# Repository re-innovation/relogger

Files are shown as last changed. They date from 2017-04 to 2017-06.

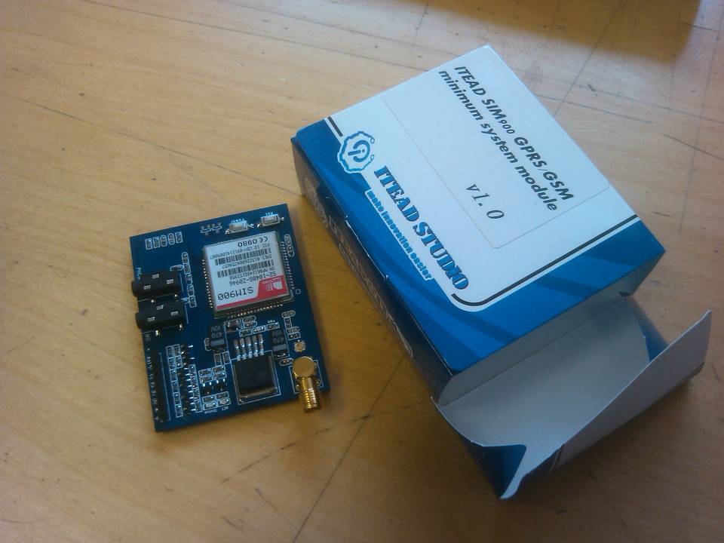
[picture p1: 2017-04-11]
relogger_Overview/GSM Equipment/GSM SIM900/Blog Post Photos/IMG_20141029_151016_copy.jpg

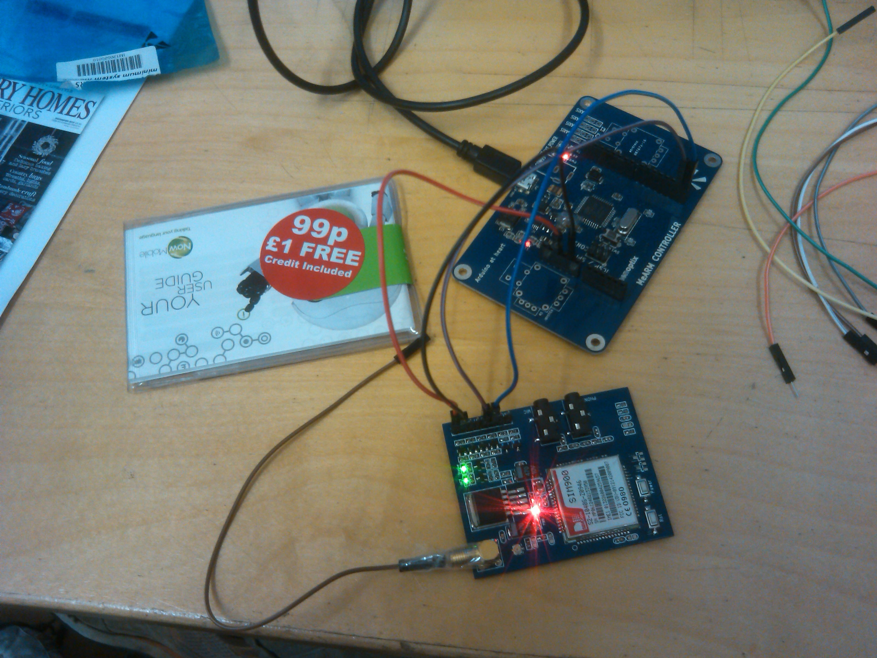
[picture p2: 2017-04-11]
relogger_Overview/GSM Equipment/GSM SIM900/Blog Post Photos/IMG_20141029_164829.jpg

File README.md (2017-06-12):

# Renewable Energy Data Logger
A multi-function renewable energy data-logger for remote logging.
This is an Arduino-based data-logger desinged to have reasanable accuracy, be low-cost, suitable for use in remote areas and to be user-friendly to set-up and use.

This is based upon work with Wind Empowerment.

This repository contains:
* An overview of the project and functions
* The Schematics and PCB design files (KiCAD)
* The Arduino control code and associated libraries
* Datasheets for all the components
* Instructions for use

# Sensors and Data
This logger can use different types of sensor attached to the inputs.

The set-up is defined on the config.txt file which must be included on the SD card.

The data required on the config.txt file is:

* Sample Time
* Sensor 1
* Sensor 2

Example config.txt file:

TO DO!

The types of sensor available are:

## Wind Speed Digital

These are conencted to a digital pin on the device.

Conversion factor required is the pulses per second to give 1m/s wind speed. 

eg: 0.6 pulse per second = 1m/s

If we read 15 pulses per second the wind speed is: 15/0.6 = 25m/s.

## Wind Speed Analog

This is connected to an analog pin.

The conversion factor is the voltage to wind speed factor.

eg. 0.1V per m/s

If we read a voltage of 0.6V then the wind speed is 0.6 / 0.1 = 6m/s

## Wind Direction

Wind direction uses a wind vane sensor with reed switches are used to introduce different resistors to the output line. Hence the output is a varying resistance, which can be measured using just one analogue pin and a potential divider.

The resistances are as follows, with all the resistors accurate to 1%. Using a potential divider of 10k for the lower resistor and a Vref of 3.3V, we can also calculate the analogue input values for each range:

* N = R1 = 33k Voltage reading = 0.76V
* NE = R2 = 8.2k Voltage reading = 1.81V
* E = R3 = 1k Voltage reading = 0.3V
* SE = R4 = 2.2k Voltage reading = 0.59V
* S = R5 = 3.9k Voltage reading = 0.92V
* SW = R6 = 16k Voltage reading = 2.03V
* W = R7 = 120k Voltage reading = 3.04V
* NW = R8 = 64.9k Voltage reading = 2.86V

## Voltage

Voltage is measured using a potential divider. R1 is the lower resistor, R2 is the top resistor.

So with R1 = 10k and R2 = 100k the real voltage is the measured voltage * (R1+R2)/(R1).

eg. V measured is 0.6V, the actual voltage will be 6.6V

We need to ensure headroom above the maximum required input voltage to ensure no damage happens to the analog input (which is protected by a zener diode). 

## Current

DC Current is measured by a range of different sensors. These generally give an output voltage which is linearly proportional to the current, but sometimes with an offset. More information here: 

https://www.re-innovation.co.uk/docs/dc-current-measurement/ 

https://www.re-innovation.co.uk/docs/acs756-current-measurements/

So we need to know the gradient and the offset for the sensor.

For the ACS758 (for example) the offset is 0.12 x Vsupply. If 5V is used as the supply voltage then the offset is 0.12 x 5 = 0.6V.
The ACS758 has a gradient of 60mV per A.

If we read 1.0V from the sensor then the conversion is: ((1.0V - offset)*1000)/ mV/A, so ((1.0-0.6)*1000)/60 = 6.66A 

The factor of 1000 converts the voltage to mV so the calculation works correctly.

## Temperature Digital

The 1-wire temeprature sensor DS18B20 is used to measure the temperature.

This requires installation of a library to read the data from this sensor, which si returned in a specific format.

## Temperature Analog

Analog temperature sensors include thermistors and thermo-couples.

These sensors will also require specific libraries to convert from the voltage readign into a temperature, as thermistors are usually non-linear.

This section needs work to implement and a decision on which type of temperature sensors uses is required.

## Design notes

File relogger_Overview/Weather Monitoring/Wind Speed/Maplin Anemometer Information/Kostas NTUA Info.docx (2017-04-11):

From 20/5/15:

(Attached Spreadsheet of data)

Hi Matt,

I managed to calibrate the anemometer. These are the calibration results:

slope offset
0.6277 0.191

The data from Ethiopia are more reasonable now.

One more question. We need to synchronize the data logger time with our DAQ card at the test site, which uses the computer time, which in turn synchronizes on the Internet.

How have you set the logger's time set?

How could we change that if needed?

Cheers
Kostas

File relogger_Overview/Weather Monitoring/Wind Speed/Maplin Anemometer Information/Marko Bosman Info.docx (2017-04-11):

From 7/5/15

Hi Matt,

this week I did my first wind measurements with the dataduino during a windy day (total one hour measurement with 1 min interval). The wind logger worked fine!

I tried to calibrate one of the cheap Maplin anemometer with an expensive (calibrated) Davis anemometer and find a big scatter, do you recognize this "trend"?:

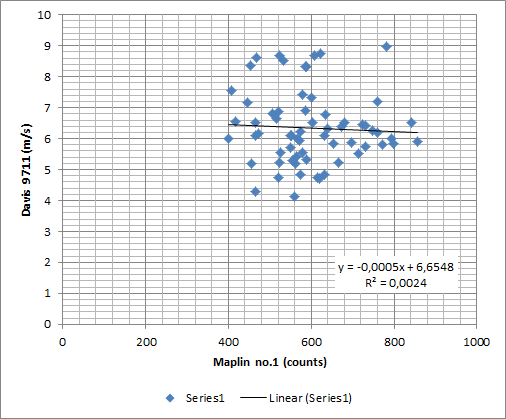
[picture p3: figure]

When I have more time again I will gather more data and will test two Maplin anemometers in parallel so I can also measure the difference between them.

keep you posted,

kind regards,

Marko Bosman

From 18/5/15:

(attached pdf)

Hi Matt,

I did some more measurements and got fairly accurate results now; see attachment. (note that the picture I have send before was wrong due to shift of time scales)

The measurement at very low windspeeds (<1 m/s) have been excluded from the dataset because the Davis anemometer is not very accurate at low wind speeds and for the purpose of wind turbine site measurements these data are not very relevant. I miss some data between 3-4 m/s, but the low and high wind speed measurements seems to correlate well. The final formula for calculating windspeed from the counts registered by the windlogger was for Anemometer 1: 0,57m/s per Hz and for Anemometer 2: 0,63m/s per Hz, somewhat different as the 0,7m/s per Hz you mentioned, but I think every Maplin anemometer is different and should be measured (periodically?).

What do you think about this procedure?

Kind regards,

Marko

From 20/5/15

(attached additional pdf)

Hi Matt,

I continued my calibration activities and finished it for 4 maplin anemometers, see attachment.

the results are pretty constant, but differ from your formula:

- Anemometer 1: 0,58 m/s per Hz
- Anemometer 2: 0,62 m/s per Hz
- Anemometer 3: 0,62 m/s per Hz
- Anemometer 4: 0,61 m/s per Hz

regards,

Marko

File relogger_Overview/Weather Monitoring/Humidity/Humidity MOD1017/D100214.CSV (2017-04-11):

Reference | Date | Time | Wind Pulses | Direction | Temperature | Humidity | Thermistor | Battery Voltage | Humidity %
AA | 10/02/2014 | 00:07:22 | 0 | D | 8.99 | 0.71084 | 10.37 | 4.44 | 71.084
AA | 10/02/2014 | 00:17:22 | 0 | D | 8.95 | 0.7117 | 10.37 | 4.44 | 71.17
AA | 10/02/2014 | 00:27:22 | 0 | D | 8.94 | 0.71218 | 10.37 | 4.44 | 71.218
AA | 10/02/2014 | 00:37:22 | 0 | D | 8.93 | 0.71218 | 10.28 | 4.44 | 71.218
AA | 10/02/2014 | 00:47:22 | 0 | D | 8.9 | 0.71237 | 10.28 | 4.44 | 71.237
AA | 10/02/2014 | 00:57:22 | 0 | D | 8.88 | 0.71279 | 10.28 | 4.44 | 71.279
AA | 10/02/2014 | 01:07:22 | 0 | D | 8.87 | 0.71279 | 10.28 | 4.44 | 71.279
AA | 10/02/2014 | 01:17:22 | 0 | D | 8.84 | 0.71304 | 10.28 | 4.44 | 71.304
AA | 10/02/2014 | 01:27:22 | 0 | D | 8.83 | 0.71322 | 10.2 | 4.43 | 71.322
AA | 10/02/2014 | 01:37:22 | 0 | D | 8.8 | 0.71322 | 10.2 | 4.43 | 71.322
AA | 10/02/2014 | 01:47:22 | 0 | D | 8.78 | 0.71347 | 10.2 | 4.43 | 71.347
AA | 10/02/2014 | 01:57:22 | 0 | D | 8.75 | 0.71347 | 10.2 | 4.43 | 71.347
AA | 10/02/2014 | 02:07:22 | 0 | D | 8.74 | 0.71408 | 10.11 | 4.43 | 71.408
AA | 10/02/2014 | 02:17:22 | 0 | D | 8.71 | 0.7145 | 10.11 | 4.43 | 71.45
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

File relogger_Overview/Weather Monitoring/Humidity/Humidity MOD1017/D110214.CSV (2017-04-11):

Reference | Date | Time | Wind Pulses | Direction | Temperature | Humidity | Thermistor | Battery Voltage
AA | 11-02-2014 | 00:00:21 | 0 | D | 10.77 | 0.64998 | 12.43 | 4.45
AA | 11-02-2014 | 00:01:21 | 0 | D | 10.76 | 0.64998 | 12.43 | 4.45
AA | 11-02-2014 | 00:02:21 | 0 | D | 10.76 | 0.64998 | 12.43 | 4.45
AA | 11-02-2014 | 00:03:21 | 0 | D | 10.76 | 0.64998 | 12.43 | 4.45
AA | 11-02-2014 | 00:04:21 | 0 | D | 10.74 | 0.65016 | 12.43 | 4.45
AA | 11-02-2014 | 00:05:21 | 0 | D | 10.74 | 0.65016 | 12.43 | 4.45
AA | 11-02-2014 | 00:06:21 | 0 | D | 10.74 | 0.65016 | 12.43 | 4.45
AA | 11-02-2014 | 00:07:21 | 0 | D | 10.73 | 0.64974 | 12.43 | 4.45
AA | 11-02-2014 | 00:08:21 | 0 | D | 10.73 | 0.65016 | 12.43 | 4.45
AA | 11-02-2014 | 00:09:21 | 0 | D | 10.73 | 0.64998 | 12.43 | 4.45
AA | 11-02-2014 | 00:10:21 | 0 | D | 10.72 | 0.64949 | 12.35 | 4.45
AA | 11-02-2014 | 00:11:21 | 0 | D | 10.72 | 0.64931 | 12.35 | 4.45
AA | 11-02-2014 | 00:12:21 | 0 | D | 10.72 | 0.65041 | 12.35 | 4.45
AA | 11-02-2014 | 00:13:21 | 0 | D | 10.70 | 0.65084 | 12.35 | 4.45
AA | 11-02-2014 | 00:14:21 | 0 | D | 10.70 | 0.65108 | 12.35 | 4.45
AA | 11-02-2014 | 00:15:21 | 0 | D | 10.70 | 0.65132 | 12.35 | 4.45
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

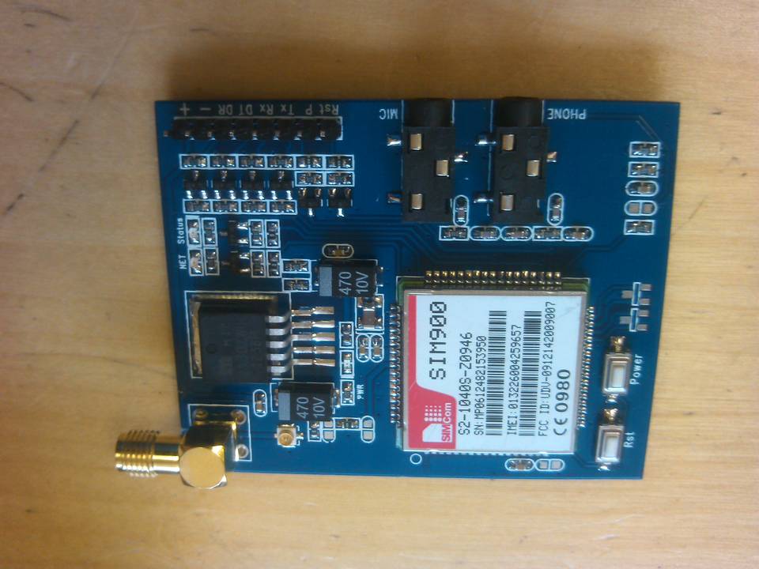
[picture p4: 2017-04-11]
relogger_Overview/GSM Equipment/GSM SIM900/Blog Post Photos/IMG_20141029_151024_copy.jpg

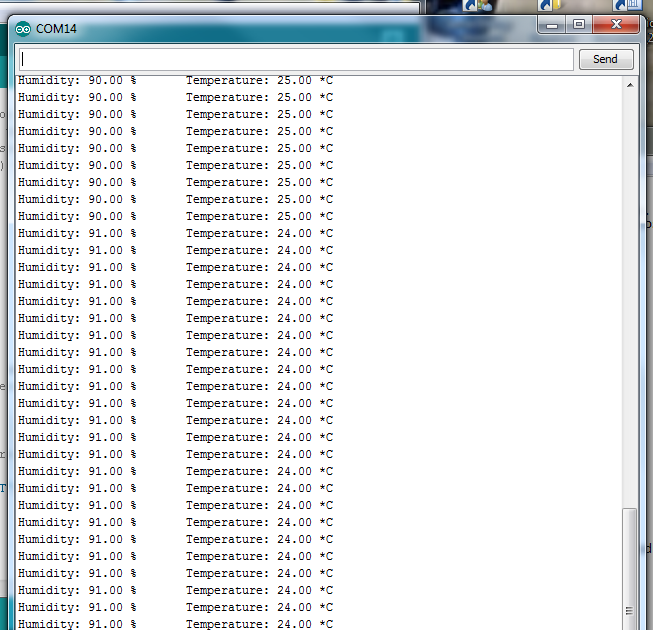
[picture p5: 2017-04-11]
relogger_Overview/Weather Monitoring/Humidity/Humidity RH11/DHT11_readings.png

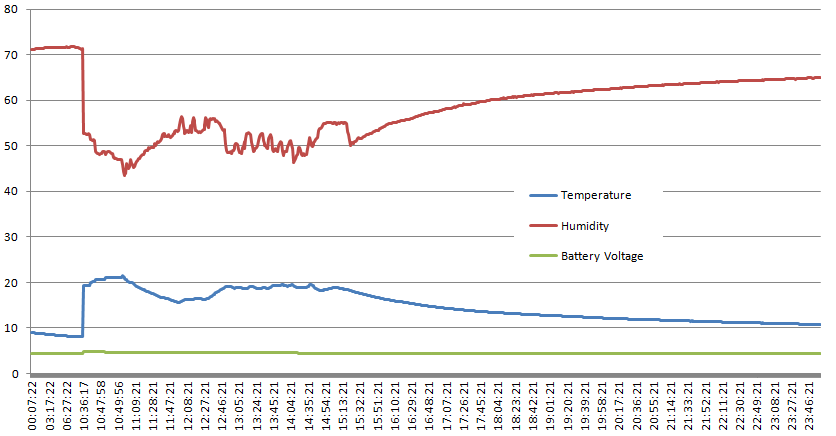
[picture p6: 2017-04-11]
relogger_Overview/Weather Monitoring/Humidity/Humidity MOD1017/TempGraph.png

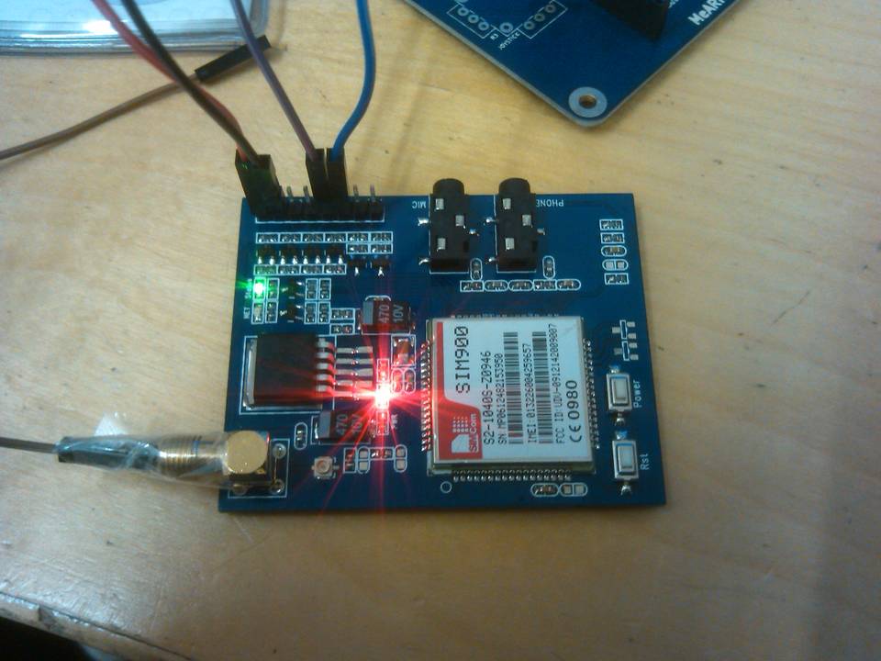
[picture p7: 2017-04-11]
relogger_Overview/GSM Equipment/GSM SIM900/Blog Post Photos/IMG_20141029_164834_copy.jpg

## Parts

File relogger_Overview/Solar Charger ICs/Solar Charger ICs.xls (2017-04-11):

Ref | IC Code | Manufacturer | Cost | Current (mA) | Voltage | Type | Package | Notes | Datasheet | Useful? | Why?
1 | N/A | AdaFruit | $17.7 | 1000 | 6 | 4.2V Li Ion |  | Module, Not IC. Uses MCP73871 | https://www.adafruit.com/product/390 | N | Module. Expensive
2 | MCP73871 | Microchip |  | 1000 | 6 | 4.2V Li Ion | 20 Lead QFN | Load Sharing IC | http://ww1.microchip.com/downloads/en/DeviceDoc/20002090C.pdf | N | Too small package
3 | MCP73831 | Microchip | 0.37 | 500 | 6 | Single Cell Li Ion | SOT-23 5 Lead | Simple. Adjustable output voltage | http://www.tme.eu/gb/Document/c098b907e182272dea149b0595062e17/mcp73831_73832.pdf | Y
4 | MCP73832 | Microchip | 0.37 | 500 | 6 | Single Cell Li Ion | SOT-23 5 Lead | As above but without tri-state output | http://www.tme.eu/gb/Document/c098b907e182272dea149b0595062e17/mcp73831_73832.pdf | Y
5 | SPV1040 | ST |  | 1500 | 0.3-5.5V | Single Cell Li Ion | TSSOP 8 | Designed for solar PV. MPPT. Needs Inductor. | http://www.st.com/content/ccc/resource/technical/document/datasheet/0d/30/c2/1a/92/03/48/cb/CD00287506.pdf/files/CD00287506.pdf/jcr:content/translations/en.CD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 | N | Not available at RS
6 | N/A | Microchip |  |  |  |  |  | Load Sharing Application Note | http://ww1.microchip.com/downloads/en/AppNotes/01149c.pdf
7 | MAX1555 | Maxim |  | 300 | 7V | Single Cell Li Ion | SOT-23-5 Lead | 2 input Li Ion Charger IC | https://www.sparkfun.com/datasheets/Components/MAX1551-MAX1555-1.pdf | Y | But Low current
8 | BQ24210 | TI | 2.26 | 800 | 20V | Single Cell Li Ion | WSON (10) | Designed for solar PV. MPPT.
9 | TP4056 | NanJing |  | 1000 | 8V | Single Cell Li Ion | SOP-8 | Design for USB input | https://dlnmh9ip6v2uc.cloudfront.net/datasheets/Prototyping/TP4056.pdf
10 | Li Po Rider Pro | SeeeedStudio |  | 1000 | 5V | Single Cell Li Ion |  | Module, Not IC. Designed for Solar and USB input. Uses CN3065 | http://www.seeedstudio.com/wiki/Lipo_Rider_Pro | N | Module
11 | CN3065 | Consonance |  | 1000 | 6V | Single Cell Li Ion |  | Used in Solar LiPo unit, but no MPPT used. | http://lib.chipdip.ru/164/DOC001164905.pdf
12 | LT1512 | Linear | 4.5 |  |  |  | DIP 8 |  | http://docs-europe.electrocomponents.com/webdocs/1364/0900766b813648fa.pdf | N | Expensive
13 | BQ2000PN-B5 | TI | 2.65 |  | 6V | Multi-Chemistry | DIP 8 | Complex external circuitry required | http://www.ti.com/lit/ds/symlink/bq2000.pdf | N | Complex additional circuitry required
14 | LT3652 | Linear | >4 | 2000 | 32V |  |  | Interesting solar charge IC | http://cds.linear.com/docs/en/datasheet/3652fe.pdf | N | Too expensive
15

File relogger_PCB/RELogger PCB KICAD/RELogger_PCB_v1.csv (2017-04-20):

Reference | Value | Footprint | Datasheet | Description | Manufacturer | Manufacturer Part No | Supplier 1 | Supplier 1 Part No | Supplier 1 Cost | Obtained?
HOLE1 | CONN_1 | REInnovationFootprint:3mm_hole_relogger |  |  |  |  |  |  |  | N/A
R1 | 470k | REInnovationFootprint:TH_Resistor_1 |  |  |  |  |  |  |  | Y
R2 | 47k | REInnovationFootprint:TH_Resistor_1 |  |  |  |  |  |  |  | Y
SW1 | CALIBRATE | REInnovationFootprint:SIL-2_large_hole |  |  |  |  |  |  |  | Y
P3 | SOLAR | REInnovationFootprint:SIL_2_screw_+_JST_2mm |  |  |  |  |  |  |  | Y
P2 | BATTERY | REInnovationFootprint:SIL_2_screw_+_JST_2mm |  |  |  |  |  |  |  | Y
P4 | A_IN_01 | matts_components:SIL-4_Grove_SIL |  |  |  |  |  |  |  | Y
PCB1 | CONN_1 |  |  |  |  |  |  |  |  | Y
LOGO1 | CONN_1 | CuriousElectric3:CEC_Globe_10mm_FCU |  |  |  |  |  |  |  | N/A
P1 | EXTERNAL PSU | REInnovationFootprint:SIL-2_screw_terminal |  |  |  |  |  |  |  | Y
P6 | I2C_1 | matts_components:SIL-4_Grove_SIL |  |  |  |  |  |  |  | Y
P7 | I2C_2 | matts_components:SIL-4_Grove_SIL |  |  |  |  |  |  |  | Y
P5 | A_IN_23 | matts_components:SIL-4_Grove_SIL |  |  |  |  |  |  |  | Y
P8 | V_EXT | REInnovationFootprint:SIL-2_screw_terminal |  |  |  |  |  |  |  | Y
D1 | 5V1 | REInnovationFootprint:TH_Diode_1 |  |  |  |  |  |  |  | Y
D2 | 5V1 | REInnovationFootprint:TH_Diode_1 |  |  |  |  |  |  |  | Y
D3 | 5V1 | REInnovationFootprint:TH_Diode_1 |  |  |  |  |  |  |  | Y
D4 | 5V1 | REInnovationFootprint:TH_Diode_1 |  |  |  |  |  |  |  | Y
P11 | SERIAL | matts_components:SIL-4_Grove_SIL |  |  |  |  |  |  |  | Y
P14 | AC_IN | REInnovationFootprint:SIL-2_screw_terminal |  |  |  |  |  |  |  | Y
K1 | ANEMOM1 | REInnovationFootprint:SIL-3_screw_terminal |  |  |  |  |  |  |  | Y
F2 | 100mA | REInnovationFootprint:TH_MC36188_FUSE
R3 | 100k | REInnovationFootprint:TH_Resistor_1 |  |  |  |  |  |  |  | Y
R4 | 100k | REInnovationFootprint:TH_Resistor_1 |  |  |  |  |  |  |  | Y
P15 | ANEMOM2 | REInnovationFootprint:SIL-2_screw_terminal |  |  |  |  |  |  |  | Y
P12 | SOFT_SERIAL | matts_components:SIL-4_Grove_SIL |  |  |  |  |  |  |  | Y
F1 | 500mA | REInnovationFootprint:TH_MC36201_FUSE
R5 | 10k | REInnovationFootprint:TH_Resistor_1 |  |  |  |  |  |  |  | Y
P10 | VANE | REInnovationFootprint:SIL-2_screw_terminal |  |  |  |  |  |  |  | Y
P9 | 3V3_VREF | REInnovationFootprint:SM_2_SLDR_JMP |  |  |  |  |  |  |  | Y
P13 | D6_D7 | matts_components:SIL-4_Grove_SIL |  |  |  |  |  |  |  | Y
DISP1 | OLED_I2C | REInnovationFootprint:TH_OLED1306
U1 | MCP3208 | REInnovationFootprint:DIP-16__300_ELL | http://docs-europe.electrocomponents.com/webdocs/1380/0900766b81380b03.pdf | 8 Channel SPI ADC 12 Bit | Microchip | MCP3208-CI/P | RS | 379-2516 | 2.716
C1 | 100n | matts_components:C1_wide_lg_pad |  |  |  |  |  |  |  | Y
P22 | A_IN_45 | matts_components:SIL-4_Grove_SIL |  |  |  |  |  |  |  | Y
P23 | AGND_GND | REInnovationFootprint:SM_2_SLDR_JMP |  |  |  |  |  |  |  | Y
D7 | 5V1 | REInnovationFootprint:TH_Diode_1 |  |  |  |  |  |  |  | Y
D5 | 5V1 | REInnovationFootprint:TH_Diode_1 |  |  |  |  |  |  |  | Y
D8 | 5V1 | REInnovationFootprint:TH_Diode_1 |  |  |  |  |  |  |  | Y
D6 | 5V1 | REInnovationFootprint:TH_Diode_1 |  |  |  |  |  |  |  | Y
D9 | 5V1 | REInnovationFootprint:TH_Diode_1 |  |  |  |  |  |  |  | Y
SW2 | SW_PUSH_SMALL_H | REInnovationFootprint:SW_PUSH_SMALL_lg_pad |  |  |  |  |  |  |  | Y
SW4 | SW_PUSH_SMALL_H | REInnovationFootprint:SW_PUSH_SMALL_lg_pad |  |  |  |  |  |  |  | Y
D17 | WS2811_EpiStar_8mm | REInnovationFootprint:TH_WS2811_LED_8mm |  |  |  |  |  |  |  | Y
EN1 | CONN_1 |  |  |  |  |  |  |  |  | N/A
LOGO2 | CONN_1 | CuriousElectric3:TCEC_Words_13mm |  |  |  |  |  |  |  | N/A
J3 | MICRO_SD | REInnovationFootprint:TH_SD_MODULE
J2 | Arduino_Nano_Header | REInnovationFootprint:NANO_DIP_30_600 |  |  |  |  |  |  |  | Y
J1 | RTC_MODULE | REInnovationFootprint:TH_RTC_MODULE
C13 | 10uF | REInnovationFootprint:C_1V7_TH |  |  |  |  |  |  |  | Y
C11 | 10uF | REInnovationFootprint:C_1V7_TH |  |  |  |  |  |  |  | Y
R17 | 2k | REInnovationFootprint:TH_Resistor_1
R16 | 470 | REInnovationFootprint:TH_Resistor_1 |  |  |  |  |  |  |  | Y
C10 | 4.7uf | REInnovationFootprint:C_1V7_TH
C14 | 4.7uf | REInnovationFootprint:C_1V7_TH
U3 | LM2574 | REInnovationFootprint:DIP-8_300_ELL | http://www.ti.com/lit/ds/symlink/lm2574.pdf | 0.5A step down DC-DC | TI | LM2574 | RS |  |  | Y
C9 | 22uF | REInnovationFootprint:C_1V7_TH |  |  |  |  |  |  |  | Y
C12 | 220uF | REInnovationFootprint:C_1V7_TH |  |  |  |  |  |  |  | Y
L1 | 330uH | REInnovationFootprint:TH_Inductor |  |  |  |  |  |  |  | Y
D10 | 1N5819 | REInnovationFootprint:TH_Diode_1 |  |  |  |  |  |  |  | Y
U5 | MCP73832 | REInnovationFootprint:SM_SOT-23-5 | http://ww1.microchip.com/downloads/en/DeviceDoc/20001984g.pdf | 500mA Linear Charge control IC | Microchip | MCP73832T-2DCI/OT | RS | 738-6629 | 0.446
D11 | D_Schottky | REInnovationFootprint:TH_Diode_1
D12 | D_Schottky | REInnovationFootprint:TH_Diode_1
Q2 | RFU9110PBF | REInnovationFootprint:TO220_P_FET | http://docs-europe.electrocomponents.com/webdocs/0791/0900766b807912ad.pdf | 3.1A P FET | Vishay | RFU9110PBF | RS | 541-1663 | 0.24
D14 | D_Schottky | REInnovationFootprint:TH_Diode_1
R18 | 100k | REInnovationFootprint:TH_Resistor_1 |  |  |  |  |  |  |  | Y
D13 | CHRG | REInnovationFootprint:TH_LED-5MM_larg_pad |  |  |  |  |  |  |  | Y
SW3 | ON/OFF | matts_components:SW_SPDT_rapid_760271 |  |  |  |  |  |  |  | Y
D18 | D_Schottky | REInnovationFootprint:TH_Diode_1
U2 | MCP1826S | REInnovationFootprint:TO220_MCP1826S
OPTO1 | VO615A | REInnovationFootprint:DIP-4_300_ELL | http://docs-europe.electrocomponents.com/webdocs/1196/0900766b81196e5a.pdf | Opto-coupler | Vishay | VO615A-5 | RS | 773-3693 | 0.12
R19 | 1k | REInnovationFootprint:TH_Resistor_1 |  |  |  |  |  |  |  | Y
D15 | 1N4001 | REInnovationFootprint:TH_Diode_1 |  |  |  |  |  |  |  | Y
R20 | 10k | REInnovationFootprint:TH_Resistor_1 |  |  |  |  |  |  |  | Y
U6 | LM393 | REInnovationFootprint:DIP-8_300_ELL | http://docs-europe.electrocomponents.com/webdocs/13e4/0900766b813e452a.pdf | Op Amp | ON Semi | LM393NG | RS | 463-870 | 0.25
RV1 | 100k | REInnovationFootprint:RV_various_lg_pad |  |  |  |  |  |  |  | Y
P26 | JMP_HALL | REInnovationFootprint:SM_2_SLDR_JMP |  |  |  |  |  |  |  | Y
D16 | 5V1 | REInnovationFootprint:TH_Diode_1 |  |  |  |  |  |  |  | Y

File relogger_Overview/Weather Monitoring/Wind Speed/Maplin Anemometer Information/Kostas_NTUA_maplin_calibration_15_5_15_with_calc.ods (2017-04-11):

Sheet: Raw Data
Reference | Date | Time | Wind1 | Wind2 | Direction | Voltage | Current1 | Current2 | Reference speed (m/s) | Expanded uncert. Uref (m/s) | average count
 |  |  |  |  |  |  |  |  | 4.023 | 0.056 | 6.1551724138
1 | 15-05-2015 | 08:21:36 | 0 | 6 | N | 15.31 | 424 | 428 | 6.082 | 0.044 | 9.0821917808
1 | 15-05-2015 | 08:21:37 | 0 | 7 | N | 10.07 | 343 | 345 | 8.13 | 0.046 | 12.632183908
1 | 15-05-2015 | 08:21:38 | 0 | 6 | N | 9.66 | 302 | 305 | 10.204 | 0.052 | 15.828125
1 | 15-05-2015 | 08:21:39 | 0 | 6 | N | 9.61 | 296 | 298 | 12.127 | 0.062 | 19.0519480519
1 | 15-05-2015 | 08:21:40 | 0 | 6 | N | 9.61 | 291 | 292 | 14.25 | 0.07 | 22.5466666667
1 | 15-05-2015 | 08:21:41 | 0 | 5 | N | 12.41 | 318 | 320 | 16.01 | 0.08 | 24.9137931034
1 | 15-05-2015 | 08:21:42 | 0 | 7 | N | 9.21 | 325 | 326 | 15.015 | 0.074 | 23.6451612903
1 | 15-05-2015 | 08:21:43 | 0 | 7 | N | 9.46 | 294 | 295 | 13.042 | 0.066 | 20.6153846154
1 | 15-05-2015 | 08:21:44 | 0 | 6 | N | 9.51 | 288 | 290 | 11.1 | 0.056 | 17.5157894737
1 | 15-05-2015 | 08:21:45 | 0 | 6 | N | 9.56 | 288 | 290 | 8.973 | 0.05 | 14.0422535211
1 | 15-05-2015 | 08:21:46 | 0 | 5 | N | 12.26 | 312 | 314 | 6.954 | 0.044 | 10.8039215686
1 | 15-05-2015 | 08:21:47 | 0 | 7 | N | 11.75 | 333 | 333 | 4.938 | 0.046 | 7.6823529412
1 | 15-05-2015 | 08:21:48 | 0 | 7 | N | 8.95 | 296 | 297
1 | 15-05-2015 | 08:21:49 | 0 | 6 | N | 9.41 | 287 | 289
1 | 15-05-2015 | 08:21:50 | 0 | 6 | N | 9.61 | 288 | 290
1 | 15-05-2015 | 08:21:51 | 0 | 5 | N | 12.26 | 309 | 311
1 | 15-05-2015 | 08:21:52 | 0 | 7 | N | 9.21 | 325 | 325
1 | 15-05-2015 | 08:21:53 | 0 | 7 | N | 9.41 | 290 | 292
1 | 15-05-2015 | 08:21:54 | 0 | 6 | N | 9.51 | 287 | 290
1 | 15-05-2015 | 08:21:55 | 0 | 6 | N | 9.61 | 286 | 288
1 | 15-05-2015 | 08:21:56 | 0 | 5 | N | 12.26 | 324 | 325
1 | 15-05-2015 | 08:21:57 | 0 | 7 | N | 9.16 | 306 | 306
1 | 15-05-2015 | 08:21:58 | 0 | 6 | N | 9.41 | 287 | 290
1 | 15-05-2015 | 08:21:59 | 0 | 6 | N | 9.56 | 288 | 289
1 | 15-05-2015 | 08:22:00 | 0 | 5 | N | 12.31 | 316 | 318
1 | 15-05-2015 | 08:22:01 | 0 | 7 | N | 9.16 | 316 | 316
1 | 15-05-2015 | 08:22:02 | 0 | 6 | N | 9.41 | 288 | 291
1 | 15-05-2015 | 08:22:03 | 0 | 6 | N | 9.51 | 289 | 291
1 | 15-05-2015 | 08:22:04 | 0 | 5 | N | 12.21 | 306 | 307
1 | 15-05-2015 | 08:22:05 | 0 | 7 | N | 11.7 | 333 | 333
1 | 15-05-2015 | 08:22:06 | 0 | 7 | N | 8.95 | 294 | 295
1 | 15-05-2015 | 08:22:07 | 0 | 6 | N | 9.36 | 286 | 289
1 | 15-05-2015 | 08:22:08 | 0 | 6 | N | 9.51 | 288 | 289
1 | 15-05-2015 | 08:22:09 | 0 | 5 | N | 12.26 | 305 | 306
1 | 15-05-2015 | 08:22:10 | 0 | 7 | N | 11.85 | 332 | 334
1 | 15-05-2015 | 08:22:11 | 0 | 7 | N | 8.95 | 305 | 306
1 | 15-05-2015 | 08:22:12 | 0 | 6 | N | 9.31 | 287 | 290
1 | 15-05-2015 | 08:22:13 | 0 | 6 | N | 9.46 | 286 | 287
1 | 15-05-2015 | 08:22:14 | 0 | 5 | N | 12.16 | 311 | 313
1 | 15-05-2015 | 08:22:15 | 0 | 7 | N | 9.05 | 308 | 308
1 | 15-05-2015 | 08:22:16 | 0 | 6 | N | 9.36 | 286 | 289
1 | 15-05-2015 | 08:22:17 | 0 | 6 | N | 9.51 | 287 | 289
1 | 15-05-2015 | 08:22:18 | 0 | 5 | N | 12.26 | 312 | 314
1 | 15-05-2015 | 08:22:19 | 0 | 7 | N | 9.16 | 320 | 320
1 | 15-05-2015 | 08:22:20 | 0 | 7 | N | 9.36 | 284 | 286
1 | 15-05-2015 | 08:22:21 | 0 | 6 | N | 9.46 | 287 | 289
1 | 15-05-2015 | 08:22:22 | 0 | 5 | N | 12.16 | 300 | 302
1 | 15-05-2015 | 08:22:23 | 0 | 7 | N | 11.75 | 329 | 330
1 | 15-05-2015 | 08:22:24 | 0 | 7 | N | 8.95 | 306 | 307
1 | 15-05-2015 | 08:22:25 | 0 | 6 | N | 9.31 | 286 | 289
1 | 15-05-2015 | 08:22:26 | 0 | 6 | N | 9.51 | 287 | 289
1 | 15-05-2015 | 08:22:27 | 0 | 5 | N | 12.21 | 308 | 310
1 | 15-05-2015 | 08:22:28 | 0 | 7 | N | 11.75 | 335 | 336
1 | 15-05-2015 | 08:22:29 | 0 | 7 | N | 8.95 | 294 | 297
1 | 15-05-2015 | 08:22:30 | 0 | 6 | N | 9.31 | 286 | 289
1 | 15-05-2015 | 08:22:31 | 0 | 6 | N | 9.46 | 287 | 288
1 | 15-05-2015 | 08:22:32 | 0 | 6 | N | 9.56 | 287 | 288
1 | 15-05-2015 | 08:22:33 | 0 | 6 | N | 12.26 | 325 | 327
1 | 15-05-2015 | 08:22:34 | 0 | 8 | N | 9.1 | 301 | 301
1 | 15-05-2015 | 08:22:35 | 0 | 7 | N | 9.36 | 298 | 299
1 | 15-05-2015 | 08:22:36 | 0 | 7 | N | 9.46 | 305 | 306
1 | 15-05-2015 | 08:22:37 | 0 | 8 | N | 12.21 | 302 | 305
1 | 15-05-2015 | 08:22:38 | 0 | 9 | N | 9 | 302 | 302
1 | 15-05-2015 | 08:22:39 | 0 | 8 | N | 9.36 | 287 | 290
1 | 15-05-2015 | 08:22:40 | 0 | 8 | N | 9.51 | 289 | 291
1 | 15-05-2015 | 08:22:41 | 0 | 7 | N | 12.16 | 299 | 300
1 | 15-05-2015 | 08:22:42 | 0 | 10 | N | 9.1 | 288 | 289
1 | 15-05-2015 | 08:22:43 | 0 | 8 | N | 9.36 | 287 | 288
1 | 15-05-2015 | 08:22:44 | 0 | 8 | N | 9.51 | 308 | 309
1 | 15-05-2015 | 08:22:45 | 0 | 9 | N | 12.21 | 318 | 321
1 | 15-05-2015 | 08:22:46 | 0 | 10 | N | 9.1 | 287 | 288
1 | 15-05-2015 | 08:22:47 | 0 | 8 | N | 9.41 | 296 | 296
1 | 15-05-2015 | 08:22:48 | 0 | 8 | N | 12.11 | 312 | 315
1 | 15-05-2015 | 08:22:49 | 0 | 10 | N | 9.1 | 297 | 297
1 | 15-05-2015 | 08:22:50 | 0 | 8 | N | 9.46 | 288 | 291
1 | 15-05-2015 | 08:22:51 | 0 | 9 | N | 9.51 | 316 | 317
1 | 15-05-2015 | 08:22:52 | 0 | 10 | N | 9.56 | 289 | 290
1 | 15-05-2015 | 08:22:53 | 0 | 9 | N | 9.66 | 288 | 290
1 | 15-05-2015 | 08:22:54 | 0 | 8 | N | 12.11 | 320 | 322
1 | 15-05-2015 | 08:22:55 | 0 | 10 | N | 9.1 | 303 | 304
1 | 15-05-2015 | 08:22:56 | 0 | 10 | N | 9.41 | 284 | 286
1 | 15-05-2015 | 08:22:57 | 0 | 8 | N | 12.21 | 307 | 309
1 | 15-05-2015 | 08:22:58 | 0 | 10 | N | 9.16 | 317 | 318
1 | 15-05-2015 | 08:22:59 | 0 | 10 | N | 9.36 | 296 | 297
1 | 15-05-2015 | 08:23:00 | 0 | 9 | N | 9.51 | 287 | 290
1 | 15-05-2015 | 08:23:01 | 0 | 9 | N | 9.61 | 289 | 291
1 | 15-05-2015 | 08:23:02 | 0 | 8 | N | 12.21 | 306 | 308
1 | 15-05-2015 | 08:23:03 | 0 | 10 | N | 11.8 | 325 | 327
1 | 15-05-2015 | 08:23:04 | 0 | 10 | N | 8.9 | 304 | 304
1 | 15-05-2015 | 08:23:05 | 0 | 10 | N | 9.36 | 284 | 286
1 | 15-05-2015 | 08:23:06 | 0 | 9 | N | 9.51 | 288 | 289
1 | 15-05-2015 | 08:23:07 | 0 | 8 | N | 12.21 | 303 | 305
1 | 15-05-2015 | 08:23:08 | 0 | 10 | N | 11.8 | 314 | 316
1 | 15-05-2015 | 08:23:09 | 0 | 10 | N | 8.95 | 315 | 316
1 | 15-05-2015 | 08:23:10 | 0 | 10 | N | 9.36 | 307 | 308
1 | 15-05-2015 | 08:23:11 | 0 | 10 | N | 9.46 | 290 | 290
1 | 15-05-2015 | 08:23:12 | 0 | 9 | N | 9.56 | 287 | 289
1 | 15-05-2015 | 08:23:13 | 0 | 9 | N | 9.61 | 289 | 291
1 | 15-05-2015 | 08:23:14 | 0 | 8 | N | 12.21 | 309 | 310
1 | 15-05-2015 | 08:23:15 | 0 | 10 | N | 9.16 | 316 | 317
1 | 15-05-2015 | 08:23:16 | 0 | 10 | N | 9.36 | 305 | 305
1 | 15-05-2015 | 08:23:17 | 0 | 10 | N | 9.46 | 289 | 290
1 | 15-05-2015 | 08:23:18 | 0 | 9 | N | 9.56 | 286 | 288
1 | 15-05-2015 | 08:23:19 | 0 | 9 | N | 9.56 | 288 | 291
1 | 15-05-2015 | 08:23:20 | 0 | 8 | N | 12.21 | 308 | 310
1 | 15-05-2015 | 08:23:21 | 0 | 10 | N | 9.05 | 317 | 317
1 | 15-05-2015 | 08:23:22 | 0 | 10 | N | 9.41 | 293 | 294
1 | 15-05-2015 | 08:23:23 | 0 | 9 | N | 9.46 | 286 | 289
1 | 15-05-2015 | 08:23:24 | 0 | 8 | N | 9.56 | 289 | 290
1 | 15-05-2015 | 08:23:25 | 0 | 10 | N | 12.21 | 307 | 309
1 | 15-05-2015 | 08:23:26 | 0 | 10 | N | 9.05 | 316 | 317
1 | 15-05-2015 | 08:23:27 | 0 | 10 | N | 9.36 | 302 | 302
1 | 15-05-2015 | 08:23:28 | 0 | 10 | N | 9.46 | 282 | 284
1 | 15-05-2015 | 08:23:29 | 0 | 9 | N | 9.56 | 289 | 290
1 | 15-05-2015 | 08:23:30 | 0 | 8 | N | 9.66 | 290 | 292
1 | 15-05-2015 | 08:23:31 | 0 | 9 | N | 12.16 | 318 | 319
1 | 15-05-2015 | 08:23:32 | 0 | 10 | N | 9.1 | 316 | 316
1 | 15-05-2015 | 08:23:33 | 0 | 10 | N | 9.36 | 286 | 290
1 | 15-05-2015 | 08:23:34 | 0 | 9 | N | 9.51 | 287 | 290
1 | 15-05-2015 | 08:23:35 | 0 | 9 | N | 9.61 | 289 | 291
1 | 15-05-2015 | 08:23:36 | 0 | 8 | N | 12.16 | 305 | 307
1 | 15-05-2015 | 08:23:37 | 0 | 10 | N | 11.8 | 315 | 317
1 | 15-05-2015 | 08:23:38 | 0 | 10 | N | 8.9 | 317 | 318
1 | 15-05-2015 | 08:23:39 | 0 | 10 | N | 9.31 | 307 | 307
1 | 15-05-2015 | 08:23:40 | 0 | 10 | N | 9.46 | 288 | 289
1 | 15-05-2015 | 08:23:41 | 0 | 9 | N | 9.51 | 286 | 288
1 | 15-05-2015 | 08:23:42 | 0 | 9 | N | 9.56 | 289 | 290
1 | 15-05-2015 | 08:23:43 | 0 | 8 | N | 9.66 | 288 | 290
1 | 15-05-2015 | 08:23:44 | 0 | 9 | N | 9.56 | 287 | 288
1 | 15-05-2015 | 08:23:45 | 0 | 10 | N | 9.56 | 287 | 288
1 | 15-05-2015 | 08:23:46 | 0 | 9 | N | 9.56 | 313 | 314
1 | 15-05-2015 | 08:23:47 | 0 | 11 | N | 9.56 | 311 | 312
1 | 15-05-2015 | 08:23:48 | 0 | 11 | N | 9.66 | 285 | 287
1 | 15-05-2015 | 08:23:49 | 0 | 11 | N | 12.26 | 311 | 313
1 | 15-05-2015 | 08:23:50 | 0 | 12 | N | 11.75 | 306 | 308
1 | 15-05-2015 | 08:23:51 | 0 | 13 | N | 8.95 | 292 | 293
1 | 15-05-2015 | 08:23:52 | 0 | 11 | N | 12 | 315 | 315
1 | 15-05-2015 | 08:23:53 | 0 | 13 | N | 9 | 309 | 310
1 | 15-05-2015 | 08:23:54 | 0 | 13 | N | 9.31 | 285 | 287
1 | 15-05-2015 | 08:23:55 | 0 | 11 | N | 12.16 | 308 | 310
1 | 15-05-2015 | 08:23:56 | 0 | 13 | N | 11.7 | 316 | 318
1 | 15-05-2015 | 08:23:57 | 0 | 13 | N | 8.9 | 309 | 310
1 | 15-05-2015 | 08:23:58 | 0 | 13 | N | 9.31 | 307 | 308
1 | 15-05-2015 | 08:23:59 | 0 | 13 | N | 12.05 | 316 | 318
1 | 15-05-2015 | 08:24:00 | 0 | 13 | N | 11.65 | 318 | 320
1 | 15-05-2015 | 08:24:01 | 0 | 13 | N | 11.55 | 317 | 318
1 | 15-05-2015 | 08:24:02 | 0 | 13 | N | 8.85 | 315 | 317
1 | 15-05-2015 | 08:24:03 | 0 | 13 | N | 11.6 | 317 | 319
1 | 15-05-2015 | 08:24:04 | 0 | 13 | N | 11.44 | 305 | 307
1 | 15-05-2015 | 08:24:05 | 0 | 13 | N | 11.55 | 310 | 312
1 | 15-05-2015 | 08:24:06 | 0 | 13 | N | 8.95 | 290 | 291
1 | 15-05-2015 | 08:24:07 | 0 | 13 | N | 9.36 | 289 | 291
1 | 15-05-2015 | 08:24:08 | 0 | 12 | N | 9.46 | 297 | 298
1 | 15-05-2015 | 08:24:09 | 0 | 13 | N | 9.56 | 302 | 302
1 | 15-05-2015 | 08:24:10 | 0 | 13 | N | 9.56 | 303 | 304
1 | 15-05-2015 | 08:24:11 | 0 | 13 | N | 9.61 | 307 | 307
1 | 15-05-2015 | 08:24:12 | 0 | 13 | N | 9.61 | 305 | 306
1 | 15-05-2015 | 08:24:13 | 0 | 13 | N | 9.61 | 303 | 303
1 | 15-05-2015 | 08:24:14 | 0 | 13 | N | 9.56 | 304 | 305
1 | 15-05-2015 | 08:24:15 | 0 | 13 | N | 9.61 | 296 | 297
1 | 15-05-2015 | 08:24:16 | 0 | 13 | N | 9.56 | 291 | 292
1 | 15-05-2015 | 08:24:17 | 0 | 13 | N | 9.61 | 289 | 290
1 | 15-05-2015 | 08:24:18 | 0 | 11 | N | 9.66 | 287 | 289
1 | 15-05-2015 | 08:24:19 | 0 | 12 | N | 12.21 | 307 | 308
1 | 15-05-2015 | 08:24:20 | 0 | 13 | N | 11.75 | 315 | 317
1 | 15-05-2015 | 08:24:21 | 0 | 13 | N | 11.49 | 318 | 320
1 | 15-05-2015 | 08:24:22 | 0 | 13 | N | 8.9 | 308 | 310
1 | 15-05-2015 | 08:24:23 | 0 | 13 | N | 9.31 | 306 | 307
1 | 15-05-2015 | 08:24:24 | 0 | 13 | N | 9.41 | 306 | 306
1 | 15-05-2015 | 08:24:25 | 0 | 13 | N | 9.56 | 290 | 291
1 | 15-05-2015 | 08:24:26 | 0 | 13 | N | 9.61 | 286 | 287
1 | 15-05-2015 | 08:24:27 | 0 | 12 | N | 9.61 | 288 | 290
1 | 15-05-2015 | 08:24:28 | 0 | 11 | N | 9.66 | 290 | 292
1 | 15-05-2015 | 08:24:29 | 0 | 12 | N | 12.26 | 306 | 308
1 | 15-05-2015 | 08:24:30 | 0 | 13 | N | 11.8 | 311 | 314
1 | 15-05-2015 | 08:24:31 | 0 | 13 | N | 11.6 | 317 | 319
1 | 15-05-2015 | 08:24:32 | 0 | 13 | N | 8.9 | 311 | 312
1 | 15-05-2015 | 08:24:33 | 0 | 13 | N | 9.36 | 308 | 310
1 | 15-05-2015 | 08:24:34 | 0 | 13 | N | 9.46 | 308 | 308
1 | 15-05-2015 | 08:24:35 | 0 | 13 | N | 9.51 | 293 | 294
1 | 15-05-2015 | 08:24:36 | 0 | 13 | N | 9.51 | 285 | 287
1 | 15-05-2015 | 08:24:37 | 0 | 12 | N | 9.56 | 287 | 289
1 | 15-05-2015 | 08:24:38 | 0 | 11 | N | 12.21 | 301 | 303
1 | 15-05-2015 | 08:24:39 | 0 | 13 | N | 11.75 | 307 | 309
1 | 15-05-2015 | 08:24:40 | 0 | 13 | N | 11.55 | 312 | 314
1 | 15-05-2015 | 08:24:41 | 0 | 13 | N | 11.44 | 318 | 320
1 | 15-05-2015 | 08:24:42 | 0 | 13 | N | 11.39 | 318 | 320
1 | 15-05-2015 | 08:24:43 | 0 | 13 | N | 8.85 | 308 | 309
1 | 15-05-2015 | 08:24:44 | 0 | 13 | N | 9.26 | 304 | 305
1 | 15-05-2015 | 08:24:45 | 0 | 13 | N | 9.41 | 298 | 299
1 | 15-05-2015 | 08:24:46 | 0 | 13 | N | 9.51 | 295 | 296
1 | 15-05-2015 | 08:24:47 | 0 | 13 | N | 9.56 | 292 | 292
1 | 15-05-2015 | 08:24:48 | 0 | 13 | N | 9.56 | 283 | 285
1 | 15-05-2015 | 08:24:49 | 0 | 12 | N | 9.61 | 290 | 291
1 | 15-05-2015 | 08:24:50 | 0 | 12 | N | 9.56 | 288 | 291
1 | 15-05-2015 | 08:24:51 | 0 | 12 | N | 9.61 | 290 | 292
1 | 15-05-2015 | 08:24:52 | 0 | 11 | N | 12.21 | 304 | 306
1 | 15-05-2015 | 08:24:53 | 0 | 13 | N | 11.75 | 310 | 312
1 | 15-05-2015 | 08:24:54 | 0 | 13 | N | 11.6 | 311 | 313
1 | 15-05-2015 | 08:24:55 | 0 | 13 | N | 11.49 | 316 | 317
1 | 15-05-2015 | 08:24:56 | 0 | 13 | N | 11.44 | 320 | 322
1 | 15-05-2015 | 08:24:57 | 0 | 13 | N | 8.85 | 309 | 310
1 | 15-05-2015 | 08:24:58 | 0 | 13 | N | 9.31 | 308 | 309
1 | 15-05-2015 | 08:24:59 | 0 | 13 | N | 9.46 | 300 | 300
1 | 15-05-2015 | 08:25:00 | 0 | 13 | N | 9.51 | 293 | 294
1 | 15-05-2015 | 08:25:01 | 0 | 13 | N | 9.56 | 287 | 289
1 | 15-05-2015 | 08:25:02 | 0 | 12 | N | 9.61 | 287 | 290
1 | 15-05-2015 | 08:25:03 | 0 | 11 | N | 12.21 | 302 | 304
1 | 15-05-2015 | 08:25:04 | 0 | 13 | N | 11.7 | 306 | 308
1 | 15-05-2015 | 08:25:05 | 0 | 13 | N | 11.6 | 315 | 317
1 | 15-05-2015 | 08:25:06 | 0 | 13 | N | 8.85 | 308 | 309
1 | 15-05-2015 | 08:25:07 | 0 | 13 | N | 9.26 | 306 | 307
1 | 15-05-2015 | 08:25:08 | 0 | 13 | N | 9.46 | 302 | 302
1 | 15-05-2015 | 08:25:09 | 0 | 13 | N | 9.56 | 294 | 295
1 | 15-05-2015 | 08:25:10 | 0 | 13 | N | 9.61 | 285 | 287
1 | 15-05-2015 | 08:25:11 | 0 | 12 | N | 9.61 | 287 | 289
1 | 15-05-2015 | 08:25:12 | 0 | 12 | N | 9.61 | 304 | 305
1 | 15-05-2015 | 08:25:13 | 0 | 13 | N | 12.21 | 297 | 300
1 | 15-05-2015 | 08:25:14 | 0 | 15 | N | 9.16 | 290 | 292
1 | 15-05-2015 | 08:25:15 | 0 | 13 | N | 9.41 | 307 | 309
1 | 15-05-2015 | 08:25:16 | 0 | 15 | N | 9.51 | 305 | 306
1 | 15-05-2015 | 08:25:17 | 0 | 15 | N | 9.51 | 304 | 302
1 | 15-05-2015 | 08:25:18 | 0 | 15 | N | 12.21 | 298 | 299
1 | 15-05-2015 | 08:25:19 | 0 | 16 | N | 9.05 | 306 | 308
1 | 15-05-2015 | 08:25:20 | 0 | 16 | N | 9.41 | 294 | 294
1 | 15-05-2015 | 08:25:21 | 0 | 15 | N | 12.11 | 297 | 300
1 | 15-05-2015 | 08:25:22 | 0 | 16 | N | 9.05 | 317 | 319
1 | 15-05-2015 | 08:25:23 | 0 | 16 | N | 8.95 | 307 | 309
1 | 15-05-2015 | 08:25:24 | 0 | 16 | N | 9.26 | 301 | 303
1 | 15-05-2015 | 08:25:25 | 0 | 16 | N | 9.41 | 300 | 300
1 | 15-05-2015 | 08:25:26 | 0 | 16 | N | 9.51 | 294 | 295
1 | 15-05-2015 | 08:25:27 | 0 | 16 | N | 9.56 | 296 | 297
1 | 15-05-2015 | 08:25:28 | 0 | 16 | N | 9.56 | 289 | 290
1 | 15-05-2015 | 08:25:29 | 0 | 16 | N | 9.56 | 287 | 289
1 | 15-05-2015 | 08:25:30 | 0 | 15 | N | 9.61 | 284 | 286
1 | 15-05-2015 | 08:25:31 | 0 | 15 | N | 12.21 | 304 | 306
1 | 15-05-2015 | 08:25:32 | 0 | 16 | N | 11.75 | 310 | 312
1 | 15-05-2015 | 08:25:33 | 0 | 16 | N | 11.44 | 319 | 321
1 | 15-05-2015 | 08:25:34 | 0 | 16 | N | 11.44 | 315 | 317
1 | 15-05-2015 | 08:25:35 | 0 | 16 | N | 8.8 | 307 | 308
1 | 15-05-2015 | 08:25:36 | 0 | 16 | N | 9.26 | 302 | 304
1 | 15-05-2015 | 08:25:37 | 0 | 16 | N | 9.41 | 301 | 303
1 | 15-05-2015 | 08:25:38 | 0 | 16 | N | 9.51 | 302 | 303
1 | 15-05-2015 | 08:25:39 | 0 | 16 | N | 9.56 | 297 | 298
1 | 15-05-2015 | 08:25:40 | 0 | 16 | N | 9.56 | 296 | 297
1 | 15-05-2015 | 08:25:41 | 0 | 16 | N | 9.61 | 289 | 290
1 | 15-05-2015 | 08:25:42 | 0 | 16 | N | 9.61 | 297 | 297
1 | 15-05-2015 | 08:25:43 | 0 | 16 | N | 9.56 | 296 | 300
1 | 15-05-2015 | 08:25:44 | 0 | 15 | N | 9.56 | 301 | 303
1 | 15-05-2015 | 08:25:45 | 0 | 16 | N | 9.56 | 300 | 300
1 | 15-05-2015 | 08:25:46 | 0 | 16 | N | 9.61 | 300 | 302
1 | 15-05-2015 | 08:25:47 | 0 | 16 | N | 9.56 | 299 | 300
1 | 15-05-2015 | 08:25:48 | 0 | 16 | N | 9.61 | 300 | 302
1 | 15-05-2015 | 08:25:49 | 0 | 16 | N | 9.61 | 301 | 301
1 | 15-05-2015 | 08:25:50 | 0 | 16 | N | 9.56 | 300 | 302
1 | 15-05-2015 | 08:25:51 | 0 | 16 | N | 9.56 | 301 | 302
1 | 15-05-2015 | 08:25:52 | 0 | 16 | N | 9.56 | 301 | 302
1 | 15-05-2015 | 08:25:53 | 0 | 16 | N | 9.61 | 301 | 302
1 | 15-05-2015 | 08:25:54 | 0 | 16 | N | 12.16 | 310 | 311
1 | 15-05-2015 | 08:25:55 | 0 | 16 | N | 9.1 | 304 | 305
1 | 15-05-2015 | 08:25:56 | 0 | 16 | N | 12.05 | 311 | 313
1 | 15-05-2015 | 08:25:57 | 0 | 16 | N | 9 | 303 | 304
1 | 15-05-2015 | 08:25:58 | 0 | 16 | N | 12 | 314 | 316
1 | 15-05-2015 | 08:25:59 | 0 | 16 | N | 9 | 305 | 307
1 | 15-05-2015 | 08:26:00 | 0 | 16 | N | 9.36 | 303 | 304
1 | 15-05-2015 | 08:26:01 | 0 | 16 | N | 9.46 | 302 | 307
1 | 15-05-2015 | 08:26:02 | 0 | 16 | N | 9.56 | 304 | 306
1 | 15-05-2015 | 08:26:03 | 0 | 16 | N | 9.51 | 301 | 302
1 | 15-05-2015 | 08:26:04 | 0 | 16 | N | 9.56 | 302 | 304
1 | 15-05-2015 | 08:26:05 | 0 | 16 | N | 9.51 | 300 | 302
1 | 15-05-2015 | 08:26:06 | 0 | 16 | N | 9.56 | 304 | 305
1 | 15-05-2015 | 08:26:07 | 0 | 16 | N | 9.56 | 300 | 304
1 | 15-05-2015 | 08:26:08 | 0 | 16 | N | 9.56 | 304 | 305
1 | 15-05-2015 | 08:26:09 | 0 | 16 | N | 9.51 | 300 | 301
1 | 15-05-2015 | 08:26:10 | 0 | 16 | N | 9.61 | 302 | 303
1 | 15-05-2015 | 08:26:11 | 0 | 16 | N | 9.51 | 300 | 301
1 | 15-05-2015 | 08:26:12 | 0 | 16 | N | 9.61 | 303 | 305
1 | 15-05-2015 | 08:26:13 | 0 | 16 | N | 9.56 | 303 | 302
1 | 15-05-2015 | 08:26:14 | 0 | 16 | N | 9.61 | 304 | 306
1 | 15-05-2015 | 08:26:15 | 0 | 16 | N | 9.51 | 302 | 300
1 | 15-05-2015 | 08:26:16 | 0 | 16 | N | 9.51 | 302 | 302
1 | 15-05-2015 | 08:26:17 | 0 | 16 | N | 9.51 | 299 | 301
1 | 15-05-2015 | 08:26:18 | 0 | 17 | N | 9.56 | 291 | 291
1 | 15-05-2015 | 08:26:19 | 0 | 17 | N | 9.56 | 297 | 301
1 | 15-05-2015 | 08:26:20 | 0 | 17 | N | 12.16 | 298 | 300
1 | 15-05-2015 | 08:26:21 | 0 | 19 | N | 9.21 | 289 | 290
1 | 15-05-2015 | 08:26:22 | 0 | 18 | N | 9.36 | 299 | 301
1 | 15-05-2015 | 08:26:23 | 0 | 19 | N | 9.46 | 302 | 300
1 | 15-05-2015 | 08:26:24 | 0 | 18 | N | 9.51 | 298 | 298
1 | 15-05-2015 | 08:26:25 | 0 | 19 | N | 12.11 | 301 | 303
1 | 15-05-2015 | 08:26:26 | 0 | 20 | N | 11.7 | 304 | 305
1 | 15-05-2015 | 08:26:27 | 0 | 21 | N | 8.9 | 296 | 297
1 | 15-05-2015 | 08:26:28 | 0 | 19 | N | 9.31 | 299 | 301
1 | 15-05-2015 | 08:26:29 | 0 | 19 | N | 9.46 | 299 | 301
1 | 15-05-2015 | 08:26:30 | 0 | 19 | N | 9.51 | 300 | 301
1 | 15-05-2015 | 08:26:31 | 0 | 19 | N | 12.21 | 307 | 309
1 | 15-05-2015 | 08:26:32 | 0 | 19 | N | 11.75 | 308 | 311
1 | 15-05-2015 | 08:26:33 | 0 | 19 | N | 11.6 | 306 | 308
1 | 15-05-2015 | 08:26:34 | 0 | 20 | N | 8.85 | 296 | 299
1 | 15-05-2015 | 08:26:35 | 0 | 19 | N | 9.36 | 287 | 289
1 | 15-05-2015 | 08:26:36 | 0 | 19 | N | 9.51 | 288 | 289
1 | 15-05-2015 | 08:26:37 | 0 | 19 | N | 9.56 | 288 | 289
1 | 15-05-2015 | 08:26:38 | 0 | 19 | N | 12.21 | 299 | 301
1 | 15-05-2015 | 08:26:39 | 0 | 20 | N | 11.75 | 302 | 304
1 | 15-05-2015 | 08:26:40 | 0 | 20 | N | 11.6 | 308 | 310
1 | 15-05-2015 | 08:26:41 | 0 | 19 | N | 11.49 | 313 | 316
1 | 15-05-2015 | 08:26:42 | 0 | 19 | N | 8.85 | 306 | 309
1 | 15-05-2015 | 08:26:43 | 0 | 19 | N | 9.26 | 304 | 306
1 | 15-05-2015 | 08:26:44 | 0 | 19 | N | 9.41 | 300 | 302
1 | 15-05-2015 | 08:26:45 | 0 | 19 | N | 9.46 | 302 | 304
1 | 15-05-2015 | 08:26:46 | 0 | 19 | N | 9.51 | 301 | 302
1 | 15-05-2015 | 08:26:47 | 0 | 18 | N | 9.56 | 294 | 294
1 | 15-05-2015 | 08:26:48 | 0 | 19 | N | 12.16 | 302 | 303
1 | 15-05-2015 | 08:26:49 | 0 | 20 | N | 9.1 | 301 | 302
1 | 15-05-2015 | 08:26:50 | 0 | 19 | N | 9.36 | 301 | 303
1 | 15-05-2015 | 08:26:51 | 0 | 19 | N | 9.51 | 300 | 302
1 | 15-05-2015 | 08:26:52 | 0 | 19 | N | 9.51 | 302 | 304
1 | 15-05-2015 | 08:26:53 | 0 | 19 | N | 9.61 | 298 | 298
1 | 15-05-2015 | 08:26:54 | 0 | 18 | N | 9.51 | 290 | 292
1 | 15-05-2015 | 08:26:55 | 0 | 19 | N | 12.21 | 297 | 300
1 | 15-05-2015 | 08:26:56 | 0 | 20 | N | 11.8 | 306 | 308
1 | 15-05-2015 | 08:26:57 | 0 | 19 | N | 11.6 | 314 | 316
1 | 15-05-2015 | 08:26:58 | 0 | 19 | N | 8.9 | 307 | 309
1 | 15-05-2015 | 08:26:59 | 0 | 19 | N | 9.31 | 305 | 305
1 | 15-05-2015 | 08:27:00 | 0 | 19 | N | 9.46 | 303 | 303
1 | 15-05-2015 | 08:27:01 | 0 | 18 | N | 9.56 | 293 | 294
1 | 15-05-2015 | 08:27:02 | 0 | 19 | N | 9.61 | 293 | 294
1 | 15-05-2015 | 08:27:03 | 0 | 20 | N | 12.16 | 300 | 302
1 | 15-05-2015 | 08:27:04 | 0 | 20 | N | 11.7 | 304 | 305
1 | 15-05-2015 | 08:27:05 | 0 | 20 | N | 11.49 | 307 | 309
1 | 15-05-2015 | 08:27:06 | 0 | 19 | N | 8.9 | 302 | 304
1 | 15-05-2015 | 08:27:07 | 0 | 19 | N | 9.31 | 300 | 305
1 | 15-05-2015 | 08:27:08 | 0 | 19 | N | 9.46 | 302 | 304
1 | 15-05-2015 | 08:27:09 | 0 | 19 | N | 9.51 | 300 | 302
1 | 15-05-2015 | 08:27:10 | 0 | 19 | N | 9.56 | 300 | 301
1 | 15-05-2015 | 08:27:11 | 0 | 19 | N | 9.56 | 298 | 298
1 | 15-05-2015 | 08:27:12 | 0 | 19 | N | 9.56 | 289 | 290
1 | 15-05-2015 | 08:27:13 | 0 | 18 | N | 12.16 | 298 | 300
1 | 15-05-2015 | 08:27:14 | 0 | 20 | N | 11.8 | 302 | 304
1 | 15-05-2015 | 08:27:15 | 0 | 20 | N | 11.55 | 310 | 312
1 | 15-05-2015 | 08:27:16 | 0 | 19 | N | 8.9 | 306 | 308
1 | 15-05-2015 | 08:27:17 | 0 | 19 | N | 9.26 | 300 | 301
1 | 15-05-2015 | 08:27:18 | 0 | 19 | N | 9.41 | 299 | 299
1 | 15-05-2015 | 08:27:19 | 0 | 19 | N | 9.46 | 295 | 296
1 | 15-05-2015 | 08:27:20 | 0 | 18 | N | 12.11 | 299 | 301
1 | 15-05-2015 | 08:27:21 | 0 | 20 | N | 11.65 | 307 | 310
1 | 15-05-2015 | 08:27:22 | 0 | 19 | N | 8.9 | 303 | 305
1 | 15-05-2015 | 08:27:23 | 0 | 19 | N | 9.26 | 303 | 301
1 | 15-05-2015 | 08:27:24 | 0 | 19 | N | 9.46 | 302 | 304
1 | 15-05-2015 | 08:27:25 | 0 | 19 | N | 9.51 | 301 | 301
1 | 15-05-2015 | 08:27:26 | 0 | 19 | N | 9.56 | 298 | 299
1 | 15-05-2015 | 08:27:27 | 0 | 19 | N | 9.56 | 290 | 291
1 | 15-05-2015 | 08:27:28 | 0 | 18 | N | 12.21 | 301 | 303
1 | 15-05-2015 | 08:27:29 | 0 | 20 | N | 11.75 | 307 | 309
1 | 15-05-2015 | 08:27:30 | 0 | 19 | N | 11.55 | 312 | 315
1 | 15-05-2015 | 08:27:31 | 0 | 19 | N | 11.55 | 315 | 317
1 | 15-05-2015 | 08:27:32 | 0 | 20 | N | 8.85 | 302 | 302
1 | 15-05-2015 | 08:27:33 | 0 | 20 | N | 9.26 | 300 | 301
1 | 15-05-2015 | 08:27:34 | 0 | 20 | N | 11.95 | 305 | 308
1 | 15-05-2015 | 08:27:35 | 0 | 22 | N | 11.7 | 308 | 309
1 | 15-05-2015 | 08:27:36 | 0 | 23 | N | 8.95 | 298 | 301
1 | 15-05-2015 | 08:27:37 | 0 | 21 | N | 11.95 | 302 | 303
1 | 15-05-2015 | 08:27:38 | 0 | 23 | N | 11.65 | 310 | 312
1 | 15-05-2015 | 08:27:39 | 0 | 23 | N | 11.55 | 306 | 309
1 | 15-05-2015 | 08:27:40 | 0 | 22 | N | 11.49 | 310 | 311
1 | 15-05-2015 | 08:27:41 | 0 | 23 | N | 11.49 | 304 | 305
1 | 15-05-2015 | 08:27:42 | 0 | 23 | N | 11.44 | 307 | 309
1 | 15-05-2015 | 08:27:43 | 0 | 23 | N | 8.9 | 296 | 297
1 | 15-05-2015 | 08:27:44 | 0 | 23 | N | 9.26 | 296 | 298
1 | 15-05-2015 | 08:27:45 | 0 | 21 | N | 12.11 | 302 | 303
1 | 15-05-2015 | 08:27:46 | 0 | 23 | N | 11.65 | 307 | 309
1 | 15-05-2015 | 08:27:47 | 0 | 23 | N | 11.6 | 304 | 306
1 | 15-05-2015 | 08:27:48 | 0 | 23 | N | 11.49 | 308 | 309
1 | 15-05-2015 | 08:27:49 | 0 | 23 | N | 11.49 | 307 | 309
1 | 15-05-2015 | 08:27:50 | 0 | 23 | N | 8.85 | 299 | 301
1 | 15-05-2015 | 08:27:51 | 0 | 22 | N | 9.31 | 301 | 303
1 | 15-05-2015 | 08:27:52 | 0 | 23 | N | 9.46 | 297 | 299
1 | 15-05-2015 | 08:27:53 | 0 | 22 | N | 9.51 | 299 | 301
1 | 15-05-2015 | 08:27:54 | 0 | 22 | N | 12.05 | 310 | 311
1 | 15-05-2015 | 08:27:55 | 0 | 23 | N | 9.16 | 300 | 303
1 | 15-05-2015 | 08:27:56 | 0 | 22 | N | 9.41 | 301 | 303
1 | 15-05-2015 | 08:27:57 | 0 | 22 | N | 9.51 | 300 | 302
1 | 15-05-2015 | 08:27:58 | 0 | 22 | N | 9.46 | 301 | 303
1 | 15-05-2015 | 08:27:59 | 0 | 23 | N | 12.21 | 306 | 307
1 | 15-05-2015 | 08:28:00 | 0 | 23 | N | 11.75 | 310 | 311
1 | 15-05-2015 | 08:28:01 | 0 | 24 | N | 8.95 | 298 | 301
1 | 15-05-2015 | 08:28:02 | 0 | 22 | N | 9.31 | 296 | 297
1 | 15-05-2015 | 08:28:03 | 0 | 22 | N | 9.46 | 300 | 298
1 | 15-05-2015 | 08:28:04 | 0 | 22 | N | 12.11 | 309 | 312
1 | 15-05-2015 | 08:28:05 | 0 | 23 | N | 11.65 | 308 | 310
1 | 15-05-2015 | 08:28:06 | 0 | 23 | N | 11.65 | 309 | 311
1 | 15-05-2015 | 08:28:07 | 0 | 23 | N | 11.55 | 308 | 309
1 | 15-05-2015 | 08:28:08 | 0 | 23 | N | 11.49 | 304 | 305
1 | 15-05-2015 | 08:28:09 | 0 | 23 | N | 8.9 | 298 | 299
1 | 15-05-2015 | 08:28:10 | 0 | 23 | N | 11.95 | 304 | 305
1 | 15-05-2015 | 08:28:11 | 0 | 23 | N | 11.6 | 306 | 308
1 | 15-05-2015 | 08:28:12 | 0 | 23 | N | 11.49 | 308 | 310
1 | 15-05-2015 | 08:28:13 | 0 | 23 | N | 8.85 | 297 | 299
1 | 15-05-2015 | 08:28:14 | 0 | 23 | N | 9.31 | 299 | 300
1 | 15-05-2015 | 08:28:15 | 0 | 23 | N | 9.46 | 296 | 298
1 | 15-05-2015 | 08:28:16 | 0 | 22 | N | 9.51 | 299 | 301
1 | 15-05-2015 | 08:28:17 | 0 | 22 | N | 9.56 | 299 | 301
1 | 15-05-2015 | 08:28:18 | 0 | 22 | N | 9.56 | 301 | 303
1 | 15-05-2015 | 08:28:19 | 0 | 22 | N | 9.51 | 300 | 302
1 | 15-05-2015 | 08:28:20 | 0 | 22 | N | 9.56 | 304 | 305
1 | 15-05-2015 | 08:28:21 | 0 | 22 | N | 9.51 | 300 | 303
1 | 15-05-2015 | 08:28:22 | 0 | 23 | N | 12.21 | 304 | 305
1 | 15-05-2015 | 08:28:23 | 0 | 23 | N | 11.65 | 308 | 309
1 | 15-05-2015 | 08:28:24 | 0 | 23 | N | 11.6 | 309 | 310
1 | 15-05-2015 | 08:28:25 | 0 | 23 | N | 8.9 | 298 | 300
1 | 15-05-2015 | 08:28:26 | 0 | 22 | N | 9.26 | 297 | 298
1 | 15-05-2015 | 08:28:27 | 0 | 22 | N | 9.41 | 296 | 298
1 | 15-05-2015 | 08:28:28 | 0 | 22 | N | 9.51 | 300 | 302
1 | 15-05-2015 | 08:28:29 | 0 | 23 | N | 12.05 | 305 | 306
1 | 15-05-2015 | 08:28:30 | 0 | 23 | N | 11.7 | 303 | 304
1 | 15-05-2015 | 08:28:31 | 0 | 23 | N | 11.55 | 306 | 310
1 | 15-05-2015 | 08:28:32 | 0 | 23 | N | 11.49 | 301 | 304
1 | 15-05-2015 | 08:28:33 | 0 | 23 | N | 11.44 | 308 | 309
1 | 15-05-2015 | 08:28:34 | 0 | 23 | N | 11.49 | 305 | 306
1 | 15-05-2015 | 08:28:35 | 0 | 23 | N | 11.39 | 307 | 309
1 | 15-05-2015 | 08:28:36 | 0 | 23 | N | 11.49 | 305 | 307
1 | 15-05-2015 | 08:28:37 | 0 | 24 | N | 8.85 | 301 | 302
1 | 15-05-2015 | 08:28:38 | 0 | 22 | N | 9.26 | 293 | 295
1 | 15-05-2015 | 08:28:39 | 0 | 22 | N | 9.51 | 300 | 302
1 | 15-05-2015 | 08:28:40 | 0 | 22 | N | 9.51 | 295 | 297
1 | 15-05-2015 | 08:28:41 | 0 | 22 | N | 9.56 | 299 | 304
1 | 15-05-2015 | 08:28:42 | 0 | 22 | N | 9.56 | 299 | 300
1 | 15-05-2015 | 08:28:43 | 0 | 22 | N | 9.56 | 299 | 298
1 | 15-05-2015 | 08:28:44 | 0 | 22 | N | 9.51 | 297 | 298
1 | 15-05-2015 | 08:28:45 | 0 | 22 | N | 9.56 | 300 | 302
1 | 15-05-2015 | 08:28:46 | 0 | 22 | N | 9.56 | 297 | 299
1 | 15-05-2015 | 08:28:47 | 0 | 22 | N | 9.56 | 299 | 301
1 | 15-05-2015 | 08:28:48 | 0 | 22 | N | 12.16 | 310 | 310
1 | 15-05-2015 | 08:28:49 | 0 | 22 | N | 9.16 | 299 | 301
1 | 15-05-2015 | 08:28:50 | 0 | 25 | N | 9.36 | 295 | 297
1 | 15-05-2015 | 08:28:51 | 0 | 24 | N | 9.46 | 297 | 298
1 | 15-05-2015 | 08:28:52 | 0 | 25 | N | 9.56 | 297 | 301
1 | 15-05-2015 | 08:28:53 | 0 | 25 | N | 12.16 | 308 | 308
1 | 15-05-2015 | 08:28:54 | 0 | 25 | N | 9.05 | 296 | 298
1 | 15-05-2015 | 08:28:55 | 0 | 24 | N | 12.05 | 309 | 310
1 | 15-05-2015 | 08:28:56 | 0 | 26 | N | 9.05 | 298 | 300
1 | 15-05-2015 | 08:28:57 | 0 | 24 | N | 11.95 | 313 | 314
1 | 15-05-2015 | 08:28:58 | 0 | 26 | N | 9 | 295 | 302
1 | 15-05-2015 | 08:28:59 | 0 | 26 | N | 9.41 | 293 | 297
1 | 15-05-2015 | 08:29:00 | 0 | 24 | N | 9.51 | 299 | 300
1 | 15-05-2015 | 08:29:01 | 0 | 24 | N | 12.11 | 313 | 314
1 | 15-05-2015 | 08:29:02 | 0 | 25 | N | 9.16 | 299 | 301
1 | 15-05-2015 | 08:29:03 | 0 | 25 | N | 9.36 | 305 | 308
1 | 15-05-2015 | 08:29:04 | 0 | 25 | N | 11.65 | 310 | 312
1 | 15-05-2015 | 08:29:05 | 0 | 26 | N | 8.95 | 297 | 299
1 | 15-05-2015 | 08:29:06 | 0 | 24 | N | 9.36 | 298 | 300
1 | 15-05-2015 | 08:29:07 | 0 | 26 | N | 9.46 | 297 | 296
1 | 15-05-2015 | 08:29:08 | 0 | 24 | N | 12.16 | 309 | 310
1 | 15-05-2015 | 08:29:09 | 0 | 26 | N | 9.1 | 296 | 299
1 | 15-05-2015 | 08:29:10 | 0 | 23 | N | 9.36 | 308 | 310
1 | 15-05-2015 | 08:29:11 | 0 | 25 | N | 11.7 | 313 | 313
1 | 15-05-2015 | 08:29:12 | 0 | 25 | N | 8.95 | 298 | 299
1 | 15-05-2015 | 08:29:13 | 0 | 25 | N | 9.31 | 295 | 298
1 | 15-05-2015 | 08:29:14 | 0 | 24 | N | 9.46 | 296 | 300
1 | 15-05-2015 | 08:29:15 | 0 | 25 | N | 9.61 | 298 | 298
1 | 15-05-2015 | 08:29:16 | 0 | 26 | N | 9.51 | 295 | 297
1 | 15-05-2015 | 08:29:17 | 0 | 25 | N | 12.16 | 310 | 310
1 | 15-05-2015 | 08:29:18 | 0 | 26 | N | 9.1 | 297 | 299
1 | 15-05-2015 | 08:29:19 | 0 | 24 | N | 9.36 | 296 | 297
1 | 15-05-2015 | 08:29:20 | 0 | 24 | N | 9.51 | 296 | 301
1 | 15-05-2015 | 08:29:21 | 0 | 24 | N | 9.51 | 299 | 301
1 | 15-05-2015 | 08:29:22 | 0 | 26 | N | 9.51 | 297 | 298
1 | 15-05-2015 | 08:29:23 | 0 | 24 | N | 9.56 | 298 | 299
1 | 15-05-2015 | 08:29:24 | 0 | 25 | N | 12.16 | 311 | 312
1 | 15-05-2015 | 08:29:25 | 0 | 26 | N | 9.05 | 295 | 297
1 | 15-05-2015 | 08:29:26 | 0 | 25 | N | 9.36 | 298 | 300
1 | 15-05-2015 | 08:29:27 | 0 | 24 | N | 9.46 | 298 | 300
1 | 15-05-2015 | 08:29:28 | 0 | 25 | N | 12.11 | 309 | 310
1 | 15-05-2015 | 08:29:29 | 0 | 26 | N | 9.05 | 296 | 299
1 | 15-05-2015 | 08:29:30 | 0 | 25 | N | 9.41 | 293 | 297
1 | 15-05-2015 | 08:29:31 | 0 | 25 | N | 9.46 | 293 | 297
1 | 15-05-2015 | 08:29:32 | 0 | 25 | N | 9.56 | 297 | 297
1 | 15-05-2015 | 08:29:33 | 0 | 25 | N | 9.46 | 294 | 296
1 | 15-05-2015 | 08:29:34 | 0 | 25 | N | 12.16 | 303 | 307
1 | 15-05-2015 | 08:29:35 | 0 | 25 | N | 11.7 | 308 | 310
1 | 15-05-2015 | 08:29:36 | 0 | 26 | N | 8.9 | 296 | 298
1 | 15-05-2015 | 08:29:37 | 0 | 24 | N | 9.31 | 297 | 299
1 | 15-05-2015 | 08:29:38 | 0 | 25 | N | 9.41 | 307 | 308
1 | 15-05-2015 | 08:29:39 | 0 | 26 | N | 9.05 | 295 | 299
1 | 15-05-2015 | 08:29:40 | 0 | 24 | N | 9.41 | 299 | 300
1 | 15-05-2015 | 08:29:41 | 0 | 25 | N | 9.46 | 295 | 298
1 | 15-05-2015 | 08:29:42 | 0 | 24 | N | 9.51 | 298 | 300
1 | 15-05-2015 | 08:29:43 | 0 | 25 | N | 12.16 | 307 | 308
1 | 15-05-2015 | 08:29:44 | 0 | 25 | N | 9.05 | 296 | 298
1 | 15-05-2015 | 08:29:45 | 0 | 26 | N | 9.41 | 295 | 296
1 | 15-05-2015 | 08:29:46 | 0 | 24 | N | 9.51 | 298 | 300
1 | 15-05-2015 | 08:29:47 | 0 | 25 | N | 12.21 | 308 | 309
1 | 15-05-2015 | 08:29:48 | 0 | 25 | N | 11.7 | 306 | 307
1 | 15-05-2015 | 08:29:49 | 0 | 25 | N | 8.9 | 297 | 299
1 | 15-05-2015 | 08:29:50 | 0 | 24 | N | 9.36 | 299 | 301
1 | 15-05-2015 | 08:29:51 | 0 | 23 | N | 12.05 | 307 | 309
1 | 15-05-2015 | 08:29:52 | 0 | 24 | N | 11.75 | 306 | 308
1 | 15-05-2015 | 08:29:53 | 0 | 25 | N | 8.95 | 298 | 302
1 | 15-05-2015 | 08:29:54 | 0 | 23 | N | 9.21 | 295 | 297
1 | 15-05-2015 | 08:29:55 | 0 | 24 | N | 12.11 | 308 | 308
1 | 15-05-2015 | 08:29:56 | 0 | 24 | N | 11.7 | 310 | 311
1 | 15-05-2015 | 08:29:57 | 0 | 25 | N | 8.95 | 297 | 300
1 | 15-05-2015 | 08:29:58 | 0 | 23 | N | 9.36 | 298 | 300
1 | 15-05-2015 | 08:29:59 | 0 | 23 | N | 9.51 | 298 | 300
1 | 15-05-2015 | 08:30:00 | 0 | 23 | N | 9.56 | 298 | 300
1 | 15-05-2015 | 08:30:01 | 0 | 24 | N | 12.11 | 306 | 307
1 | 15-05-2015 | 08:30:02 | 0 | 24 | N | 11.75 | 306 | 308
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

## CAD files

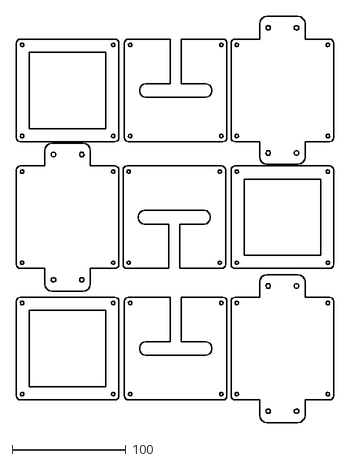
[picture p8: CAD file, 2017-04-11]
relogger_Overview/Weather Monitoring/Irradiance/PV Irradiance Sensor/2016_1_4_PV Irradiance Sensor Enclosure.dxf
278.5 x 356.6

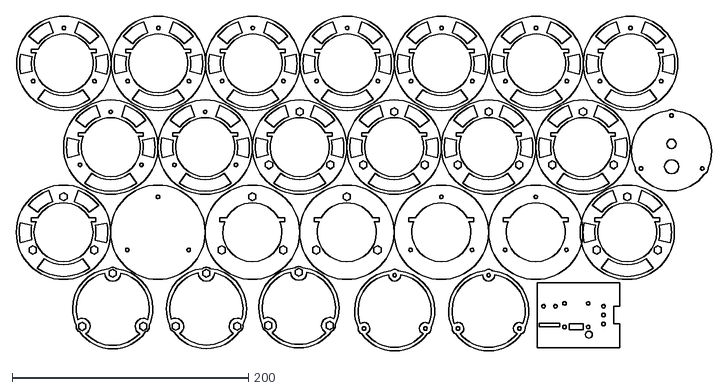
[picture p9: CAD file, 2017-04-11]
relogger_Overview/Weather Monitoring/Temperature/Temperature Sensor Shield Design/Temperature Sensor Shield_All_Parts_3mm.dxf
589.0 x 283.4

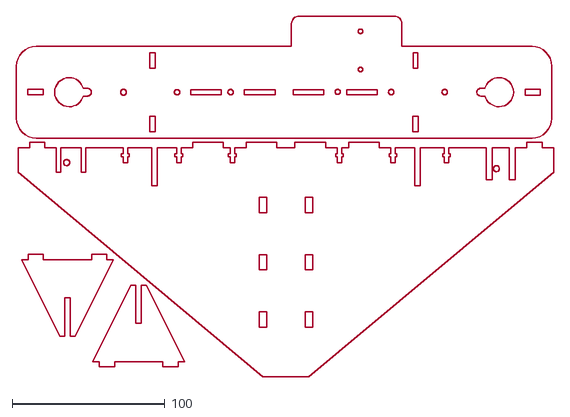
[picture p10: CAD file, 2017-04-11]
relogger_Overview/Weather Monitoring/Wind Speed/Anemometer Fixing Design/1_10_14_Wind_Logger_Anemometer_Fixing_no_measurements3.5mm_v2.dxf
351.2 x 236.0

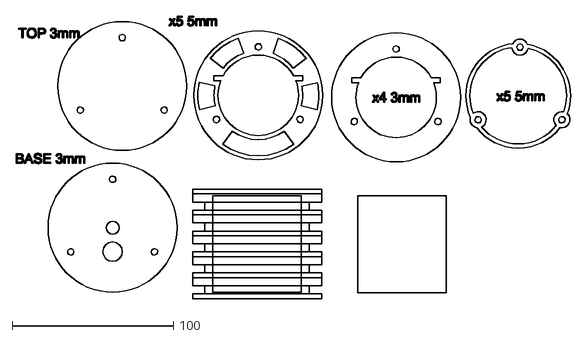
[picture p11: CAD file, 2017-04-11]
relogger_Overview/Weather Monitoring/Temperature/Temperature Sensor Shield Design/Temperature Sensor Shield.dxf
344.0 x 175.2

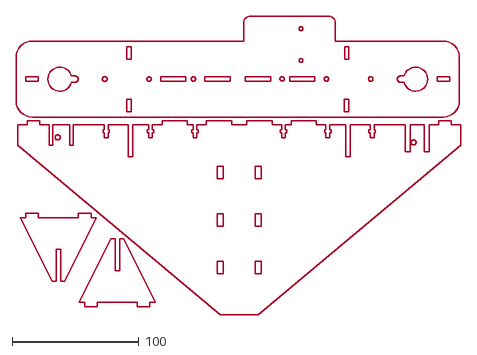
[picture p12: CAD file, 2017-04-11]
relogger_Overview/Weather Monitoring/Wind Speed/Anemometer Fixing Design/1_10_14_Wind_Logger_Anemometer_Fixing_no_measurements.dxf
351.2 x 236.0

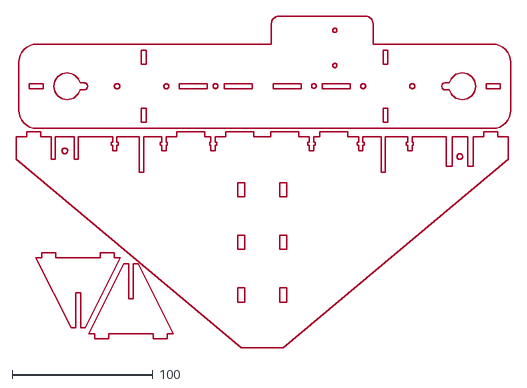
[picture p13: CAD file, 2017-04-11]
relogger_Overview/Weather Monitoring/Wind Speed/Anemometer Fixing Design/1_10_14_Wind_Logger_Anemometer_Fixing_no_measurements3.5mm.dxf
351.7 x 235.8

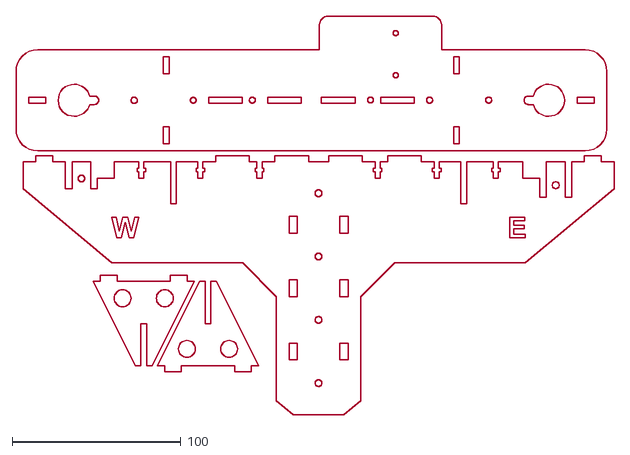
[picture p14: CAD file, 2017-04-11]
relogger_Overview/Weather Monitoring/Wind Speed/Anemometer Fixing Design/2_10_14_Wind_Logger_Anemometer_Fixing_no_measurements.dxf
354.2 x 236.1

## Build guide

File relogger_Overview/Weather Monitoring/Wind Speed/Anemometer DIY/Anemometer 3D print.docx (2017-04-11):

http://www.thingiverse.com/thing:51648

http://www.thingiverse.com/thing:34644

http://www.thingiverse.com/thing:245025

http://www.thingiverse.com/thing:338464

http://www.thingiverse.com/thing:26233

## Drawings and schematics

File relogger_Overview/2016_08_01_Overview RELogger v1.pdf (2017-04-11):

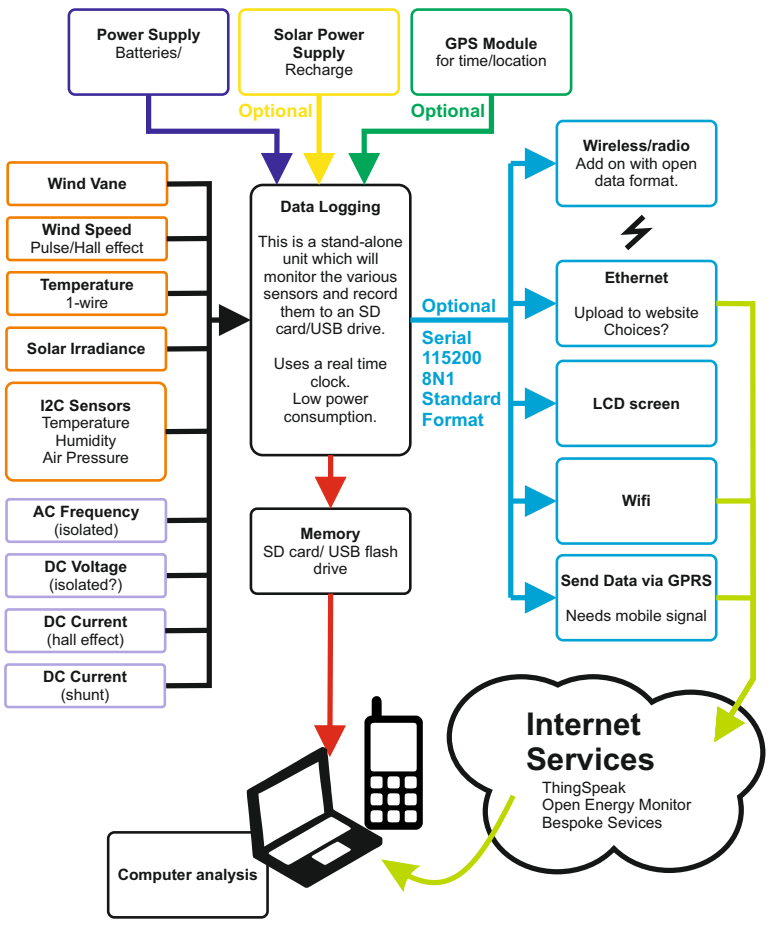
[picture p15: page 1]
I2C Sensors Temperature Humidity Air Pressure; Wind Vane; Data Logging; Ethernet; LCD screen; Computer analysis; drive; Wifi; Optional; Internet Services; Serial 115200 8N1 Standard Format; DC Voltage (isolated?); DC Current (hall effect); Solar Irradiance; DC Current (shunt); Solar Power Supply Recharge; AC Frequency (isolated); Power Supply Batteries/; Temperature 1-wire

GPS Module
for time/location

Wireless/radio
Add on with open
data format.

Wind Speed
Pulse/Hall effect

This is a stand-alone
unit which will
monitor the various
sensors and record
them to an SD
card/USB drive.

Upload to website
Choices?

Uses a real time
clock.
Low power
consumption.

Memory
SD card/ USB flash

Send Data via GPRS

Needs mobile signal

ThingSpeak
Open Energy Monitor
Bespoke Sevices

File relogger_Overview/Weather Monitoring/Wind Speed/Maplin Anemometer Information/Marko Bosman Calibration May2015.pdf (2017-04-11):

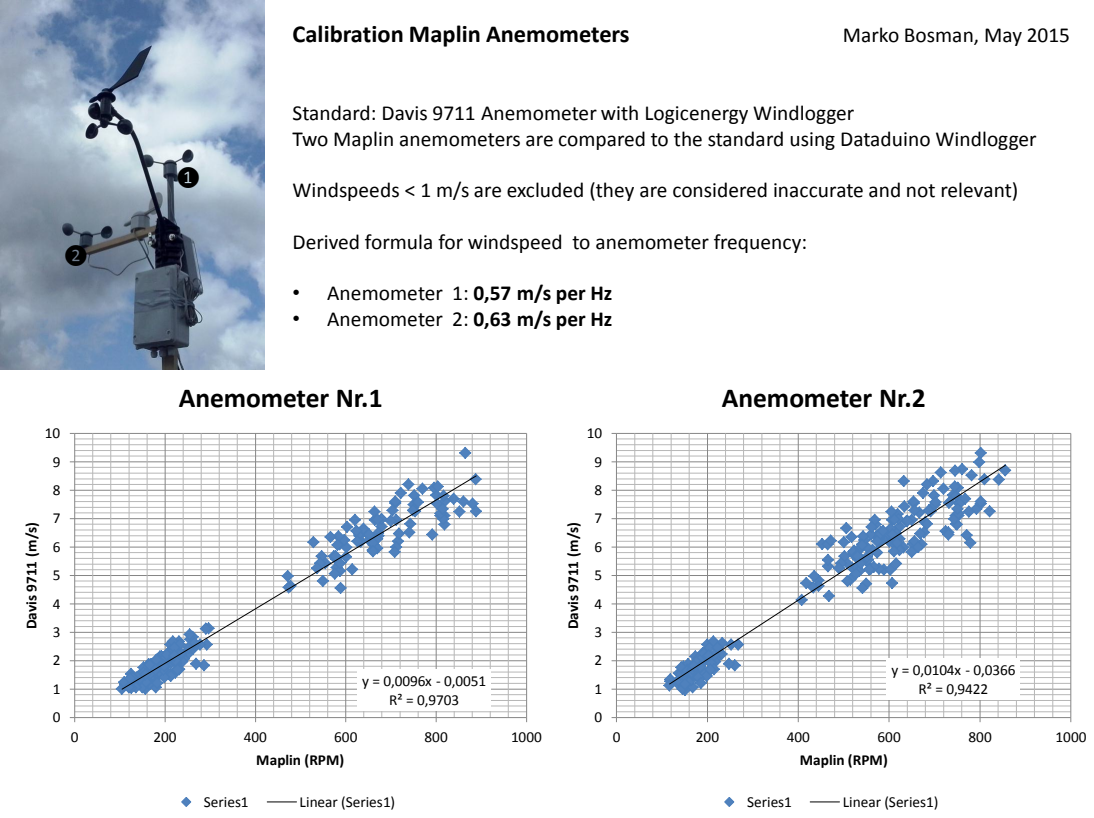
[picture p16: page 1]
Davis 9711 (m/s); Maplin (RPM); Anemometer Nr.1; Series1; Linear (Series1); Anemometer Nr.2; Calibration Maplin Anemometers; Marko Bosman, May 2015

Standard: Davis 9711 Anemometer with Logicenergy Windlogger
Two Maplin anemometers are compared to the standard using Dataduino Windlogger

Windspeeds < 1 m/s are excluded (they are considered inaccurate and not relevant)

Derived formula for windspeed to anemometer frequency:

• Anemometer 1: 0,57 m/s per Hz
• Anemometer 2: 0,63 m/s per Hz

y = 0,0104x - 0,0366
R² = 0,9422

y = 0,0096x - 0,0051
R² = 0,9703

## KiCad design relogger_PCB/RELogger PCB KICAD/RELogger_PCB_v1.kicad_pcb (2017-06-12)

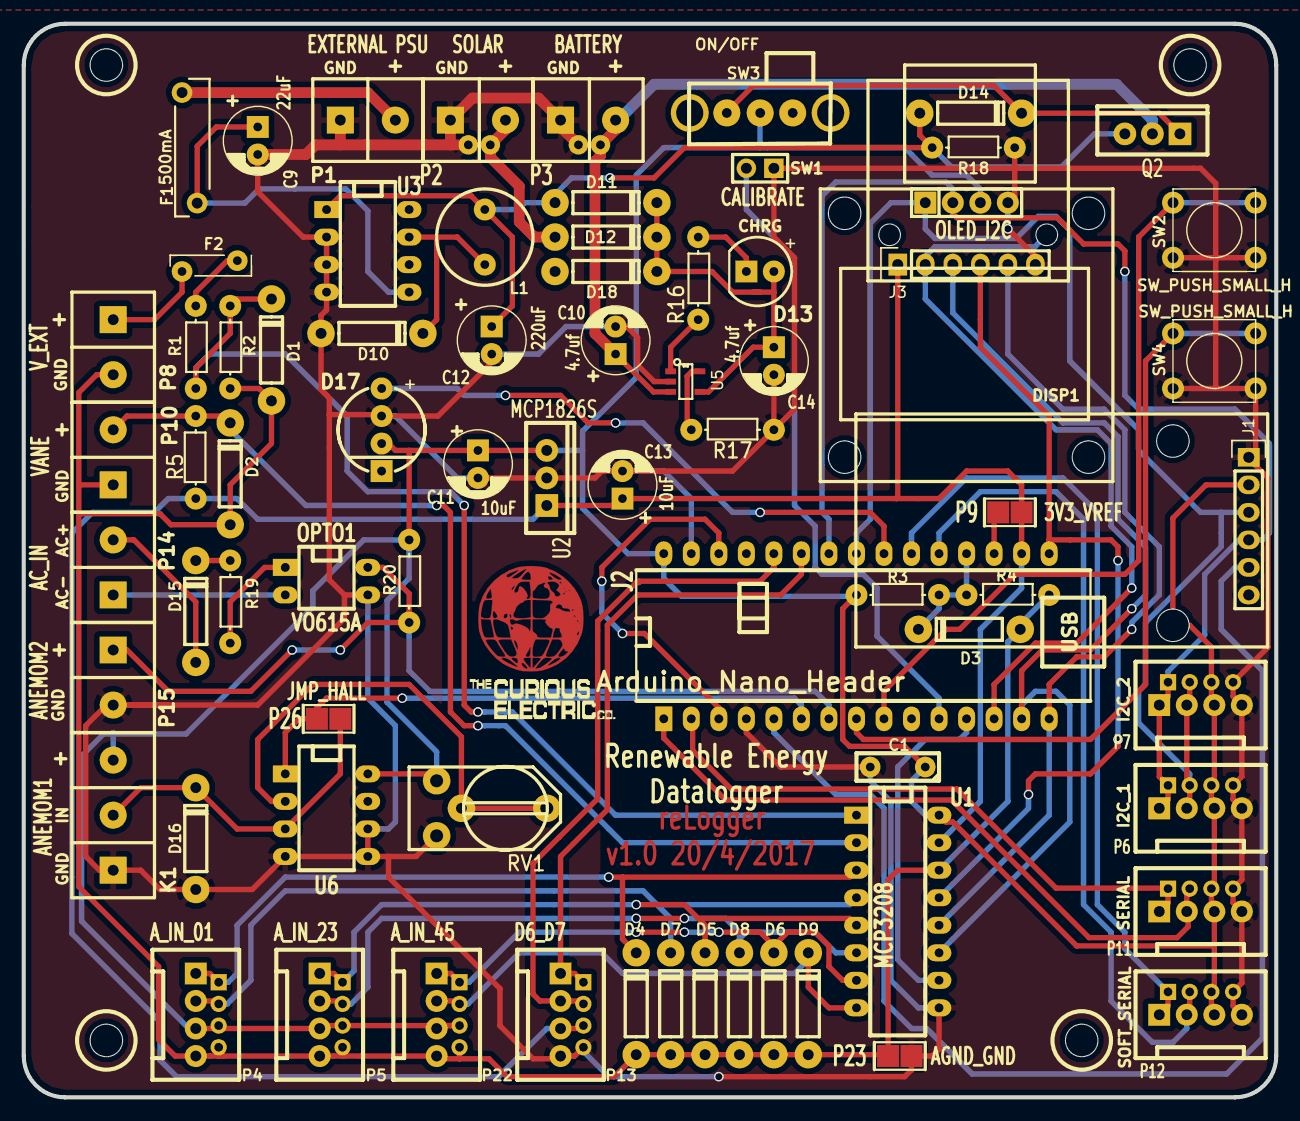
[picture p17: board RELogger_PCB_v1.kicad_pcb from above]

Board: 2 copper layers, 115.6 x 99.1 mm, 76 parts (0 on the bottom side), 54 nets.

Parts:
C1: 100n; C1_wide_lg_pad
C9: 22uF; C_1V7_TH
C10, C14: 4.7uf; C_1V7_TH
C11, C13: 10uF; C_1V7_TH
C12: 220uF; C_1V7_TH
D1, D2, D3, D4, D5, D6, D7, D8, D9, D16: 5V1; TH_Diode_1
D10: 1N5819; TH_Diode_1
D11, D12, D14, D18: D_Schottky; TH_Diode_1
D13: CHRG; TH_LED-5MM_larg_pad
D15: 1N4001; TH_Diode_1
D17: WS2811_EpiStar_8mm; TH_WS2811_LED_8mm
DISP1: OLED_I2C; TH_OLED1306
F1: 500mA; TH_MC36201_FUSE
F2: 100mA; TH_MC36188_FUSE
HOLE1: CONN_1; 3mm_hole_relogger
J1: RTC_MODULE; TH_RTC_MODULE
J2: Arduino_Nano_Header; NANO_DIP_30_600
J3: MICRO_SD; TH_SD_MODULE
K1: ANEMOM1; SIL-3_screw_terminal
L1: 330uH; TH_Inductor
LOGO1: CONN_1; CEC_Globe_10mm_FCU
LOGO2: CONN_1; TCEC_Words_13mm
OPTO1: VO615A; DIP-4_300_ELL
P1: EXTERNAL PSU; SIL-2_screw_terminal
P2: BATTERY; SIL_2_screw_+_JST_2mm
P3: SOLAR; SIL_2_screw_+_JST_2mm
P4: A_IN_01; SIL-4_Grove_SIL
P5: A_IN_23; SIL-4_Grove_SIL
P6: I2C_1; SIL-4_Grove_SIL
P7: I2C_2; SIL-4_Grove_SIL
P8: V_EXT; SIL-2_screw_terminal
P9: 3V3_VREF; SM_2_SLDR_JMP
P10: VANE; SIL-2_screw_terminal
P11: SERIAL; SIL-4_Grove_SIL
P12: SOFT_SERIAL; SIL-4_Grove_SIL
P13: D6_D7; SIL-4_Grove_SIL
P14: AC_IN; SIL-2_screw_terminal
P15: ANEMOM2; SIL-2_screw_terminal
P22: A_IN_45; SIL-4_Grove_SIL
P23: AGND_GND; SM_2_SLDR_JMP
P26: JMP_HALL; SM_2_SLDR_JMP
Q2: RFU9110PBF; TO220_P_FET
R1: 470k; TH_Resistor_1
R2: 47k; TH_Resistor_1
R3, R4, R18: 100k; TH_Resistor_1
R5, R20: 10k; TH_Resistor_1
R16: 470; TH_Resistor_1
R17: 2k; TH_Resistor_1
R19: 1k; TH_Resistor_1
RV1: 100k; RV_various_lg_pad
SW1: CALIBRATE; SIL-2_large_hole
SW2, SW4: SW_PUSH_SMALL_H; SW_PUSH_SMALL_lg_pad
SW3: ON/OFF; SW_SPDT_rapid_760271
U1: MCP3208; DIP-16__300_ELL
U2: MCP1826S; TO220_MCP1826S
U3: LM2574; DIP-8_300_ELL
U5: MCP73832; SM_SOT-23-5
U6: LM393; DIP-8_300_ELL

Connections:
+3.3V: C13.1, J2.17, J3.1, P9.1, P13.3, R5.1, U1.15, U2.3
/A0: D4.1, P4.1, U1.3
/A1: D7.1, P4.2, U1.4
/A2: D5.1, P5.1, U1.5
/A3: D8.1, P5.2, U1.6
/A4: D6.1, P22.1, U1.7
/A5: D9.1, P22.2, U1.8
/A6: J2.25, P13.1
/A7: J2.26, P13.2
/AC_to_Freq/AC_IN+: D15.2, P14.2
/AC_to_Freq/AC_IN-: OPTO1.2, P14.1
/Arduino Uno/D8: J2.11, SW1.2
/Arduino Uno/RESET: J2.3, J2.28
/Arduino Uno/VREF: J2.18, P9.2
/CLK_ADC: J2.16, J3.4, U1.13
/CLK_INT: J1.5, J2.5
/CS_ADC: J2.12, U1.10
/DIN_ADC: J2.14, J3.3, U1.11
/DOUT_ADC: J2.15, J3.5, U1.12
/Hall_to_freq/Hall_In: D16.1, K1.2, P26.1, U6.3
/IN_ACFREQ: J2.7, OPTO1.4, P15.1, R20.2
/IN_AN1: J2.6, P26.2, U6.1
/LED_WS2811: D17.4, J2.22
/Power Supply/BATT+: C10.1, P2.2, Q2.2, U5.3
/Power Supply/EXTERNAL+: C9.1, F1.2, U3.5
/Power Supply/SOLAR+: D12.2, P3.2
/Rx: J2.2, P11.1
/Rx_SOFT: J2.21, P12.1
/SCLK: DISP1.2, J1.4, J2.24, P6.1, P7.1
/SDA: DISP1.1, J1.3, J2.23, P6.2, P7.2
/SD_CS: J2.13, J3.2
/SW_A: J2.8, SW4.1
/SW_B: J2.9, SW2.1
/Tx: J2.1, P11.2
/Tx_SOFT: J2.20, P12.2
/VANE: D2.1, P10.2, R5.2, U1.2
/VBATT: D3.1, J2.19, R3.2, R4.1
/VEXT: D1.1, R1.2, R2.1, U1.1
/Vss: C1.1, C11.1, D17.2, DISP1.3, J1.2, J2.30, K1.3, P4.3, P5.3, P6.3, P7.3, P11.3, P12.3, P22.3, R3.1, R20.1, RV1.1, SW3.2, U1.16, U2.1, U6.8
GND: C1.2, C9.2, C10.2, C11.2, C12.2, C13.2, C14.2, D10.2, D16.2, D17.3, DISP1.4, J1.1, J2.4, J2.29, J3.6, K1.1, OPTO1.3, P1.1, P2.1, P3.1, P6.4, P7.4, P11.4, P12.4, P13.4, P15.2, P23.1, R17.2, R18.2, RV1.3, SW1.1, SW2.2, SW4.2, U1.9, U2.2, U3.2, U3.3, U3.4, U5.2, U6.4, U6.5, U6.6
GNDA: D1.2, D2.2, D3.2, D4.2, D5.2, D6.2, D7.2, D8.2, D9.2, P4.4, P5.4, P8.2, P10.1, P22.4, P23.2, R2.2, R4.2, U1.14
unnamed: C12.1, D11.2, D14.2, L1.2, Q2.1, R18.1, U3.1
unnamed: C14.1, D11.1, D12.1, D13.2, D18.1, U5.4
unnamed: D10.1, L1.1, U3.7
unnamed: D13.1, R16.1
unnamed: D14.1, Q2.3, SW3.1
unnamed: D15.1, R19.1
unnamed: F1.1, P1.2
unnamed: F2.1, P8.1
unnamed: F2.2, R1.1
unnamed: OPTO1.1, R19.2
unnamed: R16.2, U5.1
unnamed: R17.1, U5.5
unnamed: RV1.2, U6.2

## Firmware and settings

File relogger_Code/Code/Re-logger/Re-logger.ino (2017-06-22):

#include <Adafruit_NeoPixel.h>

#include <EEPROMex.h>

#include <SPI.h>

#include <SdFat.h>
#include <SdFatConfig.h>

#include <DS3231.h>

#include <OneWire.h>
#include <DallasTemperature.h>

#include <avr/sleep.h>
#include <avr/power.h>
#include <avr/wdt.h>
#include <avr/pgmspace.h>

#include <PinChangeInt.h>

#include <Mcp3208.h>

#define RGB_LED_PIN    6
#define NUMPIXELS      1

#define SD_CS_PIN      10

#define ONE_WIRE_BUS   7        // Choose a default PIN

#define DOWN_BUTTON    5

#define RTC_INT_PIN    2

#define SPI_CS      9        // SPI slave select
#define ADC_VREF    3300     // 3.3V Vref
#define ADC_CLK     1600000  // SPI clock 1.6MHz

DS3231  rtc(A4, A5);

OneWire oneWire(ONE_WIRE_BUS);
DallasTemperature sensors(&oneWire);

Adafruit_NeoPixel pixels = Adafruit_NeoPixel(NUMPIXELS, RGB_LED_PIN, NEO_GRB + NEO_KHZ800);

SdFat SD;
File myFile;

MCP3208 adc(ADC_VREF, SPI_CS);

char justCreated = 0;
int cptBuff1 = 0;
int cptPulse1 = 0;
int cptBuff2 = 0;
int cptPulse2 = 0;
int cptST = 0;
char rtc_flag = 0;
volatile int f_wdt=1; 

char firstTimeWS1 = 1;
char firstTimeWS2 = 1;

char flagWriteData = 0;

int sampleTime = 0;

int dataNumber = -1;
char pathMes[15];

// Structure that stores the informations for one value to measure
struct dataToRead {
  int dataPin;
  char dataName[4];
  char dataType[2];
  float dataCal1;
  float dataCal2;
  char dataUnit[3];
  char dataAD;
};

// Array that stores all the informations about the data to measure got from the parsed config file
dataToRead fileFormat[10];

// Array that stores the sensorValues
int sensorValues[10];

// Array that stores the measured values after the conversion from sensorValues to measuredValues
float measuredValues[10];

char firstTime[10] = {1,1,1,1,1,1,1,1,1,1};

/*********************************************************/
void setup() {
  // put your setup code here, to run once:
  char valid = 0;

  /*
   * Begin() of all libraries
   */  
  
  Serial.begin(115200);
  while (!Serial) {
    ; // wait for serial port to connect. Needed for native USB port only
  }

  sensors.begin();
  
  pixels.begin(); 
  
  if (!SD.begin(SD_CS_PIN)) {
    Serial.println("error init sd");
    return;
  }

  rtc.begin();

  /*
   * Init the MCP3208 (A to D converter)
   */
   
   pinMode(SPI_CS, OUTPUT);
   digitalWrite(SPI_CS, HIGH);
   SPISettings settings(ADC_CLK, MSBFIRST, SPI_MODE0);
   SPI.begin();
   SPI.beginTransaction(settings);

  /*
   * Set the date
   */
   
  do{
  valid = setDte();
  }while(valid == 0);

  /*
   * Init the watchdog timer
   */

  MCUSR &= ~(1<<WDRF);                                          // Clear the reset flag  
  WDTCSR |= (1<<WDCE) | (1<<WDE);                               // In order to change WDE or the prescaler, we need to set WDCE (This will allow updates for 4 clock cycles).
  WDTCSR = 0<<WDP3 | 1<<WDP2 | 0<<WDP1 | 0<<WDP0;               // Set new watchdog timeout prescaler value (0.250 seconds)
  WDTCSR |= _BV(WDIE);                                          // Enable the WD interrupt (note no reset)

  /*
   * Read config file and parse it
   */

  if (!SD.chdir("Re-Logger", true)) {
    Serial.println("Already");
  }
    
  getFileFormat();

  delay(1000);

  /*
   * Create a file if doesn't exists
   */
   
  checkFileDate();

  delay(1000);
   
  /*
   * Init the RTC "interrupt"
   */  
     
  rtc.setOutput(OUTPUT_SQW);
  rtc.setSQWRate(SQW_RATE_1);
  pinMode(RTC_INT_PIN, INPUT);

  attachInterrupt(digitalPinToInterrupt(RTC_INT_PIN), rtc_ISR, RISING);

  /*
   * Set sleep mode
   */
  
  set_sleep_mode(SLEEP_MODE_PWR_DOWN);
}

void loop() {
  String pathDate;
    
  if(rtc_flag == 1)
  {
    rtc_flag = 0;

    // Update the pulses's buffers and reset the pulses's counters
    cptBuff1 = cptPulse1;
    cptBuff2 = cptPulse2;
    cptPulse1 = 0;
    cptPulse2 = 0;
  
    // Read data
    readSensorValues();

    // Convert the value form raw sensor values to the measured values
    conversion();
    
    // Check if write data
    if (cptST >= sampleTime)
    {
      for (int i=0; i<=dataNumber; i++)
      {
        firstTime[i] = 1;
      }
      cptST = 0;
      flagWriteData = 1;
      
    }
  }
  
  // Enable sleep
  sleep_enable();
  //Serial.print("enter sleep");
  //Serial.flush();
  sleep_mode();
  
  // Disable sleep
  sleep_disable();
  //Serial.print("awake");
  power_all_enable();
  
  if(f_wdt == 1)
  {
    if(flagWriteData == 1)
    {
      flagWriteData = 0;
      
      // Check file
      checkFileDate();
      
      // Write data on file
      writeDataOnFile();
    }
    f_wdt = 0;

    // Update LED


    // Check switches
    
    
  }  
}

///////////////////////////////////////////////////////////////////////////////////////////////////////////////
///////////////////////////////////////////////////////////////////////////////////////////////////////////////
///////////////////////////////////////////////////////////////////////////////////////////////////////////////

void rtc_ISR ()
{
  if(rtc_flag == 0)
  {
    rtc_flag = 1;
  }
  cptST++;
}

void pulse1_ISR ()
{
  cptPulse1++;
}

void pulse2_ISR ()
{
  cptPulse2++;
}

ISR(WDT_vect)                             //Watchdog Interrupt Service. This is executed when watchdog timed out
{
  if(f_wdt == 0)
  {
    f_wdt=1; 
  }
  else
  {
    
  }
}

/*
 * Print an error message in the config file
 */
 
void error()
{
  Serial.println("error");
  Serial.println("re-write config");
}

/*
 * The user sets the date
 */
 
char setDte()
{
  char valid = 0;
  int dOw = 0;
  int ho=0;
  int ho_d=0;
  int ho_u=0;
  int mi=0;
  int mi_d=0;
  int mi_u=0;
  int se=0;
  int se_d=0;
  int se_u=0;
  int da=0;
  int da_d=0;
  int da_u=0;
  int mo=0;
  int mo_d=0;
  int mo_u=0;
  int ye=0;
  int ye_m=0;
  int ye_c=0;
  int ye_d=0;
  int ye_u=0;
  //set the date
  Serial.println(" ");
  Serial.println("set the date:");
  Serial.print("day of the week : ");
  do{
    do{
    dOw = Serial.read()-48;
    }while(dOw <0);
    if((dOw>=1) && (dOw<=7))
    {
      valid = 1;
      Serial.println(dOw);
    }
    else
    {
      return(0);
    }
  }while(valid == 0);
  valid = 0;
  rtc.setDOW(dOw);     // Set Day-of-Week to SUNDAY
  Serial.print("hour : ");
  do{
      do{
        ho_d = Serial.read()-48;
      }while(ho_d <0);
      Serial.print(ho_d);
      do{
      ho_u = Serial.read()-48;
      }while(ho_u <0);
      ho = 10*ho_d + ho_u;
      if((ho>=0) && (ho<=24))
      {
        valid = 1;
        Serial.println(ho_u);
      }
      else
      {
        return(0);
      }
  }while(valid == 0);
  valid = 0;
  Serial.print("minutes : ");
  do{
      do{
         mi_d = Serial.read()-48;
       }while(mi_d <0);
      Serial.print(mi_d);
      do{
      mi_u = Serial.read()-48;
      }while(mi_u <0);
      mi = 10*mi_d + mi_u;
      if((mi>=0) && (mi<=60))
      {
        valid = 1;
        Serial.println(mi_u);
      }
      else
      {
        return(0);
      }
  }while(valid == 0);
  valid = 0;
  Serial.print("seconds : ");
  do{
      do{
        se_d = Serial.read()-48;
      }while(se_d <0);
      Serial.print(se_d);
      do{
      se_u = Serial.read()-48;
      }while(se_u <0);
      se = 10*se_d + se_u;
      if((se>=0) && (se<=60))
      {
        valid = 1;
        Serial.println(se_u);
      }
      else
      {
        return(0);
      }
  }while(valid == 0);
  valid = 0;
  Serial.print("day of the month : ");
    do{
      do{
        da_d = Serial.read()-48;
       }while(da_d <0);
      Serial.print(da_d);
      do{
      da_u = Serial.read()-48;
      }while(da_u <0);
      da = 10*da_d + da_u;
      if((da>=0) && (da<=31))
      {
        valid = 1;
        Serial.println(da_u);
      }
      else
      {
        return(0);
      }
  }while(valid == 0);
  valid = 0;
  Serial.print("month : ");
  do{
      do{
        mo_d = Serial.read()-48;
      }while(mo_d <0);
      Serial.print(mo_d);
      do{
      mo_u = Serial.read()-48;
      }while(mo_u <0);
      mo = 10*mo_d + mo_u;
      if((mo>=0) && (mo<=12))
      {
        valid = 1;
        Serial.println(mo_u);
      }
      else
      {
        return(0);
      } 
  }while(valid == 0);
  valid = 0;
  Serial.print("year : ");
  do{
    do{
    ye_m = Serial.read()-48;
    }while(ye_m <0);
    Serial.print(ye_m);
    do{
    ye_c = Serial.read()-48;
    }while(ye_c <0);
    Serial.print(ye_c);
    do{
    ye_d = Serial.read()-48;
    }while(ye_d <0);
    Serial.print(ye_d);
      do{
        ye_u = Serial.read()-48;
      }while(ye_u <0);
      ye = 1000*ye_m + 100*ye_c + 10*ye_d + ye_u;
      if((ye>=0) && (ye<=3000))
      {
        valid = 1;
        Serial.println(ye_u);
      }
      else
      {
        return(0);
      }
  }while(valid == 0);
  valid = 0;
  rtc.setTime(ho, mi, se);     // Set the time to 12:00:00 (24hr format)
  rtc.setDate(da, mo, ye);
  return(1);
}

/*
 * Parsing algorithm of the config file
 */
 
bool getFileFormat ()   //parameters Sample Time, fileFormat and dataNumber
{
  char c = 0;
  char str[5] = {0,0,0,0,0};
  char buff[5] = {'\0','\0','\0','\0','\0'};
  int cpt = 0;
  int i = 0;
  bool valid = false;
  bool pass;
  
  myFile = SD.open("config.txt");
  
  while (myFile.available())
  {
    pass = false;
    do{
      c = myFile.read();   
      if (c == '$')
      {
         pass = true;
         //Serial.print("ok1");
      }
    }while (pass == false);
    pass = false;
    // Sample time
    do{
      c = myFile.read();
      if ((c >= '0') && (c <= '9') && (cpt < 4))
      {
        str[cpt] = c;
        cpt++;
        //Serial.print("ok2");
      }
      else if ((c == ';') && (cpt <= 4))
      {
        for (i = 0; i<cpt; i++)
        {
          buff[i] = str[i];
        }
        sampleTime = atoi(buff);
        for (i = 0; i<cpt; i++)
        {
          str[i] = 0;
        }
        for (i = 0; i<5; i++)
        {
          buff[i] = '\0';
        }
        cpt = 0;
        pass = true;
        //Serial.print("ok3");
      }
      else 
      {
        error();
        return (false);
      }
    }while (pass == false);
    while (valid == false)
    {
      pass = false;
      do{
        c = myFile.read();
        if (c == '$')
        {
          dataNumber ++;
          pass = true;
          //Serial.print("ok4");
        }
        else if (c == '#')
        {
          //Serial.println("ok5");
          valid = true;
          return (true);
        }
        else if (c == '\r')
        {
          pass = false;
        }
        else if (c == '\n')
        {
          pass = false;
        }
        else
        {
          error();
          return (false);
        }
      }while (pass == false);
      pass = false;
    // analog/digital
      do{
        c = myFile.read();
        if((c != ';') && (cpt < 1))
        {
          str[cpt] = c;
          cpt++;
          //Serial.print("ok18");
        }
        else if ((c == ',') && (cpt <= 1))
        {
          //Serial.print("ok19");
          for (i = 0; i<cpt; i++)
          {
            fileFormat[dataNumber].dataAD = str[i];
          }
          for (i = 0; i<cpt; i++)
          {
            str[i] = 0;
          }
          cpt = 0;
          pass = true;
        }
        else
        {
          error();
          return (false);
        }
      }while (pass == false);
      pass = false;
      // Pin
      do{
        c = myFile.read();
        if ((c>='0') && (c<='9') && (cpt < 2))
        {
          str[cpt] = c;
          cpt++;
          //Serial.print("ok6");
        }
        else if ((c == ',') && (cpt <= 2))
        {
          for (i = 0; i<cpt; i++)
          {
            buff[i] = str[i];
          }
          fileFormat[dataNumber].dataPin = atoi(buff);
          for (i = 0; i<cpt; i++)
          {
            str[i] = 0;
          }
          for (i = 0; i<5; i++)
          {
            buff[i] = '\0';
          }
          cpt = 0;
          pass = true;
          //Serial.print("ok7");
        }
        else
        {
          error();
          return (false);
        }
      }while (pass == false);
      pass = false;
      // Name
      do{
        c = myFile.read();
        if ((c != ',') && (cpt < 4))
        {
          str[cpt] = c;
          cpt ++;
          //Serial.print("ok8");
        }
        else if ((c = ',') && (cpt <= 4))
        {
          for (i = 0; i < cpt; i++)
          {
            fileFormat[dataNumber].dataName[i] = str[i];
          }
          for (i = 0; i<cpt; i++)
          {
            str[i] = 0;
          }
          cpt = 0;
          pass = true;
          //Serial.print("ok9");
        }
        else
        {
          error();
          return (false);
        }
      }while (pass == false);
      pass = false;
      // Type
      do{
        c = myFile.read();
        if ((c != ',') && (cpt < 2))
        {
          str[cpt] = c;
          cpt ++;
          //Serial.print("ok10");
        }
        else if ((c = ',') && (cpt <= 2))
        {
          for (i = 0; i < cpt; i++)
          {
            fileFormat[dataNumber].dataType[i] = str[i];
          }
          for (i = 0; i<cpt; i++)
          {
            str[i] = 0;
          }
          cpt = 0;
          pass = true;
          //Serial.print("ok11");
        }
        else
        {
          error();
          return (false);
        }
      }while (pass == false);
      pass = false;
      // calibration 1
      do{
        c = myFile.read();
        if ((((c>='0') && (c<='9')) || c=='.') && (c!=',') && (cpt<4))
        {
          str[cpt] = c;
          cpt ++;
          //Serial.print("ok12");
        }
        else if ((c = ',') && (cpt <= 4))
        {
          for (i = 0; i<cpt; i++)
          {
            buff[i] = str[i];
          }
          fileFormat[dataNumber].dataCal1 = atof(buff);
          for (i = 0; i<cpt; i++)
          {
            str[i] = 0;
          }
          for (i = 0; i<5; i++)
          {
            buff[i] = '\0';
          }
          cpt = 0;
          pass = true;
          //Serial.print("ok13");
        }
        else
        {
          error();
          return (false);
        }
      }while (pass == false);
      pass = false;
      // calibration 2
      do{
        c = myFile.read();
        if ((((c>='0') && (c<='9')) || c=='.') && (c!=',') && (cpt<4))
        {
          str[cpt] = c;
          cpt ++;
          //Serial.print("ok14");
        }
        else if ((c = ',') && (cpt <= 4))
        {
          for (i = 0; i<cpt; i++)
          {
            buff[i] = str[i];
          }
          fileFormat[dataNumber].dataCal2 = atof(buff);
          for (i = 0; i<cpt; i++)
          {
            str[i] = 0;
          }
          for (i = 0; i<5; i++)
          {
            buff[i] = '\0';
          }
          cpt = 0;
          pass = true;
          //Serial.print("ok15");
        }
        else
        {
          error();
          return (false);
        }
      }while (pass == false);
      pass = false;
      // Unit
      do{
        c = myFile.read();
        if ((c!=';') && (cpt<3))
        {
          str[cpt] = c;
          cpt ++;
          //Serial.print("ok16");
        }
        else if ((c == ';') && (cpt <= 1))
        {
          //Serial.print("ok17");
          for (i = 0; i<cpt; i++)
          {
            fileFormat[dataNumber].dataUnit[i] = str[i];
          }
          for (i = 0; i<cpt; i++)
          {
            str[i] = 0;
          }
          cpt = 0;
          pass = true;
        }
        else
        {
          error();
          return (false);
        }
      }while (pass == false);
      
    }
  }
}

/*
 * Reads the raw sensor values
 */

void readSensorValues() // parameters sensorValues[], fileFormat and dataNumber
{
  int i = 0;
  int j = 0;

  for(i = 0; i <= dataNumber; i++)
  {
    if (fileFormat[i].dataType[0] == 'T')
    {
      if (fileFormat[i].dataAD == 'D')
      {
        sensors.requestTemperatures();
      }
    }
    else if ((fileFormat[i].dataType[0] == 'W') && (fileFormat[i].dataType[1] == 'S'))
    {
      if (fileFormat[i].dataAD == 'D')
      {
        // nothing
      }
    }
    else
    {
      if (fileFormat[i].dataAD == 'D')
      {
        sensorValues[i] = digitalRead(fileFormat[i].dataPin);
        for(j = 0; j < 25; j++)
          sensorValues[i] = ((sensorValues[i] + digitalRead(fileFormat[i].dataPin)) / 2);
      }
      else if (fileFormat[i].dataAD == 'A')
      {
        switch(fileFormat[i].dataPin)
        {
          case 0: 
          {
            sensorValues[i] = adc.read(MCP3208::SINGLE_0);
            Serial.println(sensorValues[i]);
            Serial.flush();
            for(j = 0; j < 25; j++)
              sensorValues[i] = ((sensorValues[i] + adc.read(MCP3208::SINGLE_0)) / 2);
          }
          break;
          case 1:
          {
            sensorValues[i] = adc.read(MCP3208::SINGLE_1);
            for(j = 0; j < 25; j++)
              sensorValues[i] = ((sensorValues[i] + adc.read(MCP3208::SINGLE_1)) / 2);
          }
          break;
          case 2:
          {
            sensorValues[i] = adc.read(MCP3208::SINGLE_2);
            for(j = 0; j < 25; j++)
              sensorValues[i] = ((sensorValues[i] + adc.read(MCP3208::SINGLE_2)) / 2);
          }
          break;
          case 3:
          {
            sensorValues[i] = adc.read(MCP3208::SINGLE_3);
            for(j = 0; j < 25; j++)
              sensorValues[i] = ((sensorValues[i] + adc.read(MCP3208::SINGLE_3)) / 2);
          }
          break;
          case 4:
          {
            sensorValues[i] = adc.read(MCP3208::SINGLE_4);
            for(j = 0; j < 25; j++)
              sensorValues[i] = ((sensorValues[i] + adc.read(MCP3208::SINGLE_4)) / 2);
          }
          break;
          case 5:
          {
            sensorValues[i] = adc.read(MCP3208::SINGLE_5);
            for(j = 0; j < 25; j++)
              sensorValues[i] = ((sensorValues[i] + adc.read(MCP3208::SINGLE_5)) / 2);
          }
          break;
          case 6:
          {
            sensorValues[i] = adc.read(MCP3208::SINGLE_6);
            for(j = 0; j < 25; j++)
              sensorValues[i] = ((sensorValues[i] + adc.read(MCP3208::SINGLE_6)) / 2);
          }
          break;
          case 7:
          {
            sensorValues[i] = adc.read(MCP3208::SINGLE_7);
            for(j = 0; j < 25; j++)
              sensorValues[i] = ((sensorValues[i] + adc.read(MCP3208::SINGLE_7)) / 2);
          }
          break;
          default:
          {
            //nothing
          }
        }
        
      }
    }
  }
}

/*
 * Does the conversion from raw values to measured values
 */
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

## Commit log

2017-04-11 First commit of main info
    [1_10_14_Wind_Logger_Anemometer_Fixing_no_measurements.dxf, 1_10_14_Wind_Logger_Anemometer_Fixing_no_measurements3.5mm.dxf, 1_10_14_Wind_Logger_Anemometer_Fixin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]
2017-04-13 Schematic uploaded with Arduino Nano, SD Card connector and DS3231 connector
    [AC_to_Freq.sch, ArduinoUno.sch, Hall_to_freq.sch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]
2017-04-13 Merge remote-tracking branch 'origin/master'
    # Conflicts:
    # relogger_PCB/RELogger PCB KICAD/AC_to_Freq.sch
    # relogger_PCB/RELogger PCB KICAD/ArduinoUno.sch
    # relogger_PCB/RELogger PCB KICAD/Hall_to_freq.sch
    # relogger_PCB/RELogger PCB KICAD/RELogger_PCB_v1-cache.lib
    # relogger_PCB/RELogger PCB KICAD/RELogger_PCB_v1.bak
    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
2017-04-13 Update of schematic
    By ML
    [AC_to_Freq.sch, ArduinoUno.sch, Hall_to_freq.sch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]
2017-04-14 Schematic update and PCB initial run
    [AC_to_Freq.sch, ArduinoUno.sch, Hall_to_freq.sch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]
2017-04-18 PCB Linking
    [RELogger_PCB_v1.kicad_pcb]
2017-04-20 Small PCB updates
    [RELogger_PCB_v1-B.Mask.gbs, RELogger_PCB_v1-B.SilkS.gbo, RELogger_PCB_v1-Back.gbl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]
2017-04-20 BOM uploaded
    [AC_to_Freq.sch, ArduinoUno.sch, Hall_to_freq.sch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]
2017-04-20 Small update
    [RELogger_PCB_v1.kicad_pcb]
2017-04-20 Revert "Small update"
    This reverts commit fabb74e8d79b427a73ffd518ee6a77bfb9482e12.
    # relogger_PCB/RELogger PCB KICAD/RELogger_PCB_v1.kicad_pcb-bak
    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
    [RELogger_PCB_v1.kicad_pcb]
2017-04-20 Re load of new PCB
    [AC_to_Freq.sch, ArduinoUno.sch, Hall_to_freq.sch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]
2017-04-20 BOM done
    [RELogger_PCB_v1.csv]
2017-04-20 BOM updated
    [RELogger_PCB_v1.csv, RELogger_PCB_v1.kicad_pcb, RELogger_PCB_v1.sch]
2017-06-12 update of PCB
    [RELogger_PCB_v1.kicad_pcb, RELogger_PCB_v1.sch]
2017-06-12 flow diagram
